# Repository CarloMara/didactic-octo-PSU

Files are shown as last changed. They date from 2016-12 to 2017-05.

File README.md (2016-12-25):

# **Didactic PSU**

**An efficient finals project**

So, @nicogela and I decided to build a LAB PSU, but because we're lazy people and we don't like to carry weight we're tring to unite the high efficiency of the switching topologies to the high stability and low noise of the linear ones.

Up until now we've designed the linear stage, and we added to it some DACs in oreder to controll it with a uC. The next stage in the design process will be the testing of the linear + the dacs. If everithing works we will go ahead adding to the desing the switching stage.

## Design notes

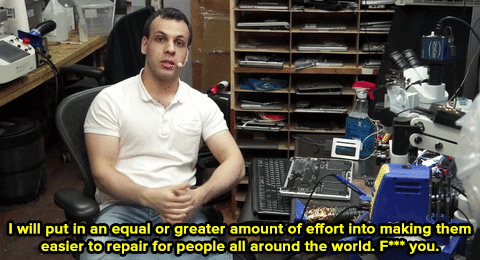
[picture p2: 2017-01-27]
datasheet-docs/low_voltage_switching/fuck_you.gif

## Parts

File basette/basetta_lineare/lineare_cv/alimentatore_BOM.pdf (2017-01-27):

alimentatore

Refs | Value
C14;C12;C13 | .33u
C2 | 0
C3 | 180p
C18 | 18p
C4 | 2200p
C5 | 6.8u
C1 | 1000u
C6 | 470u
C8;C7 | NP
C11;C10;C16;C17;C9;C15470u
D1;D3;D2;D6;D8;D4;D5 | 1N4148
D7 | D_Small
U3 | LM393
U1;U2;U4 | LM741
P8;P9 | CONN_01X01
J10 | TP1
J11 | TP2
J12 | TP3
J2 | TP5
J1 | TP6
J3 | TP7
P5 | CONN_01X02
P4;P7 | CONN_01X03
P3 | CONN_01X04
RV1;RV2 | 10K
RV3 | 50K
U7 | LM7805CT
U8 | LM7812CT
U9 | LM7912CT
R29;R28 | 1K
R2;R7;R21 | 0
R19 | 0,1
R17 | 1
R26 | 100K
R20;R22 | 10K
R9;R13;R23 | 1K
R4 | 1K2
R6 | 1M5
R8;R10 | 2,5K
R12 | 21,5
R2 | 2K
R16 | 390
R24 | 4,64K
R3 | 50
R18 | 500K
R11 | 50K
R5 | 5K
R15 | 6,81K
R27 | 900K
R25 | NP
R14 | R
L1 | 0

Q1 | Q_NMOS_GDS
Q2 | Q_PNP_EBC
P1 | LOAD_POWER_01X02
P2 | CONN_01X03
P6 | LOGIC_POWER_01X03

Footprint | QTY | MFR | MPN | SPR | SPN
Capacitors_ThroughHole:C_Disc_D3_P2.5 | 3
Capacitors_ThroughHole:C_Disc_D3_P2.5 | 1
Capacitors_ThroughHole:C_Disc_D3_P2.5 | 1
Capacitors_ThroughHole:C_Disc_D3_P2.5 | 1
Capacitors_ThroughHole:C_Disc_D3_P2.5 | 1
Capacitors_ThroughHole:C_Disc_D3_P2.5 | 1
Capacitors_ThroughHole:C_Radial_D14_L31.5_P5 | 1
Capacitors_ThroughHole:C_Radial_D14_L31.5_P5 | 1
Capacitors_ThroughHole:C_Radial_D7.5_L11.2_P2.5 | 2
Capacitors_ThroughHole:C_Radial_D8_L21_P3.8 | 6
Diodes_ThroughHole:Diode_DO-41_SOD81_Vertical_AnodeUp | 7
Diodes_ThroughHole:Diode_DO-41_SOD81_Vertical_AnodeUp | 1
Housings_DIP:DIP-8_W7.62mm_LongPads | 1
Housings_DIP:DIP-8_W7.62mm_LongPads | 3
Pin_Headers:Pin_Header_Straight_1x01 | 2
Pin_Headers:Pin_Header_Straight_1x01 | 1
Pin_Headers:Pin_Header_Straight_1x01 | 1
Pin_Headers:Pin_Header_Straight_1x01 | 1
Pin_Headers:Pin_Header_Straight_1x01 | 1
Pin_Headers:Pin_Header_Straight_1x01 | 1
Pin_Headers:Pin_Header_Straight_1x01 | 1
Pin_Headers:Pin_Header_Straight_1x02 | 1
Pin_Headers:Pin_Header_Straight_1x03 | 2
Pin_Headers:Pin_Header_Straight_1x04 | 1
Potentiometers:Potentiometer_Trimmer-Piher-PT15-h5_vertical | 2
Potentiometers:Potentiometer_Trimmer-Piher-PT15-h5_vertical | 1
Power_Integrations:TO-220 | 1
Power_Integrations:TO-220 | 1
Power_Integrations:TO-220 | 1
Resistors_SMD:R_1210_HandSoldering | 2
Resistors_ThroughHole:Resistor_Horizontal_RM10mm | 3
Resistors_ThroughHole:Resistor_Horizontal_RM10mm | 1
Resistors_ThroughHole:Resistor_Horizontal_RM10mm | 1
Resistors_ThroughHole:Resistor_Horizontal_RM10mm | 1
Resistors_ThroughHole:Resistor_Horizontal_RM10mm | 2
Resistors_ThroughHole:Resistor_Horizontal_RM10mm | 3
Resistors_ThroughHole:Resistor_Horizontal_RM10mm | 1
Resistors_ThroughHole:Resistor_Horizontal_RM10mm | 1
Resistors_ThroughHole:Resistor_Horizontal_RM10mm | 2
Resistors_ThroughHole:Resistor_Horizontal_RM10mm | 1
Resistors_ThroughHole:Resistor_Horizontal_RM10mm | 1
Resistors_ThroughHole:Resistor_Horizontal_RM10mm | 1
Resistors_ThroughHole:Resistor_Horizontal_RM10mm | 1
Resistors_ThroughHole:Resistor_Horizontal_RM10mm | 1
Resistors_ThroughHole:Resistor_Horizontal_RM10mm | 1
Resistors_ThroughHole:Resistor_Horizontal_RM10mm | 1
Resistors_ThroughHole:Resistor_Horizontal_RM10mm | 1
Resistors_ThroughHole:Resistor_Horizontal_RM10mm | 1
Resistors_ThroughHole:Resistor_Horizontal_RM10mm | 1
Resistors_ThroughHole:Resistor_Horizontal_RM10mm | 1
Resistors_ThroughHole:Resistor_Horizontal_RM10mm | 1
Resistors_ThroughHole:Resistor_Horizontal_RM7mm | 1

TO_SOT_Packages_THT:TO-220_Neutral123_Vertical_LargePad | 1
TO_SOT_Packages_THT:TO-92_Rugged | 1
w_conn_screw:mors_2p | 1
w_conn_screw:mors_3p | 1
w_conn_screw:mors_3p | 1

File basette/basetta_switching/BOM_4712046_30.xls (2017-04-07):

Part | Manufacturer | Part Number | Quantity | Price | Attribute 1 Name | Attribute 1 Value | Attribute 2 Name | Attribute 2 Value | Attribute 3 Name | Attribute 3 Value | Footprint
Cbias | TDK | C3216X7R2A105M160AA | 1 | 0.11 |  | CAP CER 1UF 100V X7R 1206 |  |  |  |  | 1206
Cboot1 | Kemet | C0603C104K3RACTU | 1 | 0.01 |  | CAP CER 0.1UF 25V X7R 0603 |  |  |  |  | 603
Cboot2 | Kemet | C0603C104K3RACTU | 1 | 0.01 |  |  |  |  |  |  | 603
Cbulk | Nichicon | UUD1C680MCL1GS | 1 | 0.11 |  | CAP ALUM 68UF 20% 16V SMD |  |  |  |  | SM_RADIAL_6.3AMM
Ccomp | MuRata | GRM033R61A822KA01D | 1 | 0.01 |  | CAP CER 8200PF 10V X5R 0201 |  |  |  |  | 201
Ccomp2 | Kemet | C0805C270K5GACTU | 1 | 0.01 |  | CAP CER 27PF 50V NP0 0805 |  |  |  |  | 805
Ccs | AVX | 06035A470JAT2A | 1 | 0.01 |  | CAP CER 47PF 50V NP0 0603 |  |  |  |  | 603
Cf | TDK | C1608X5R1H224K080AB | 1 | 0.03 |  | CAP CER 0.22UF 50V X5R 0603 |  |  |  |  | 603
Cin | MuRata | GRM31CR71E106KA12L | 1 | 0.05 |  | CAP CER 10UF 25V X7R 1206 |  |  |  |  | 1206_190
Cout | TDK | CGA9P3X7S2A156M250KB | 2 | 1.24 |  | CAP CER 15UF 100V X7S 2220 |  |  |  |  | 2220_280
Coutx | TDK | C5750X7R2A475M | 5 | 0.67 |  | CAP CER 4.7UF 100V X7R 2220 |  |  |  |  | 2220
Coutx2 | TDK | C5750X7R2A475M | 5 | 0.67 |  |  |  |  |  |  | 2220
Coutx3 | TDK | C5750X7R2A475M | 5 | 0.67 |  |  |  |  |  |  | 2220
Cslope | Yageo America | CC0603JRNPO9BN271 | 1 | 0.01 |  | CAP CER 270PF 50V NPO 0603 |  |  |  |  | 603
Css | Kemet | C0603C223K3RACTU | 1 | 0.01 |  | CAP CER 0.022UF 25V X7R 0603 |  |  |  |  | 603
Cvcc | MuRata | GRM188R61C105KA93D | 1 | 0.01 |  | CAP CER 1UF 16V X5R 0603 |  |  |  |  | 603
D2 | Fairchild Semiconductor | SS24FL | 1 | 0.07 | VFatIo | 0.55V | Io | 2A | VRRM | 40V | SOD-123F
D3 | Diodes Inc. | B260-13-F | 1 | 0.09 | VFatIo | 0.7V | Io | 2A | VRRM | 60V | SMB
Dboot1 | Fairchild Semiconductor | SS24FL | 1 | 0.07 | VFatIo | 0.55V | Io | 2A | VRRM | 40V | SOD-123F
Dboot2 | Fairchild Semiconductor | SS24FL | 1 | 0.07 | VFatIo | 0.55V | Io | 2A | VRRM | 40V | SOD-123F
Df | Fairchild Semiconductor | SS24FL | 1 | 0.07 | VFatIo | 0.55V | Io | 2A | VRRM | 40V | SOD-123F
L1 | Coilcraft | XAL1010-822MEB | 1 | 1.71 | L | 8.2uH | DCR | 0.012Ohm | IDC | 17.1A | XAL1010
M1 | Texas Instruments | CSD16323Q3 | 1 | 0.36 | VdsMax | 25V | IdsMax | 60A | Rdson | 4.4mOhm | DQG0008A
M2 | Texas Instruments | CSD16323Q3 | 1 | 0.36 | VdsMax | 25V | IdsMax | 60A | Rdson | 4.4mOhm | DQG0008A
M3 | Texas Instruments | CSD19534Q5A | 1 | 0.34 | VdsMax | 100V | IdsMax | 50A | Rdson | 0.014Ohm | TRANS_NexFET_Q5A
M4 | Texas Instruments | CSD18531Q5A | 1 | 0.58 | VdsMax | 60V | IdsMax | 100A | Rdson | 5.8mOhm | TRANS_NexFET_Q5A
Rcomp | Vishay-Dale | CRCW040241K2FKED | 1 | 0.01 | Resistance | 41.2kOhm | Tolerance | 1% | Power | 0.063W | 402
Rcsg | Vishay-Dale | CRCW0603100RFKEA | 1 | 0.01 | Resistance | 100Ohm | Tolerance | 1% | Power | 0.1W | 603
Rcsp | Vishay-Dale | CRCW0603100RFKEA | 1 | 0.01 | Resistance | 100Ohm | Tolerance | 1% | Power | 0.1W | 603
Rf | Vishay-Dale | CRCW060310R0FKEA | 1 | 0.01 | Resistance | 10Ohm | Tolerance | 1% | Power | 0.1W | 603
Rfbb | Vishay-Dale | CRCW060320K0FKEA | 1 | 0.01 | Resistance | 20kOhm | Tolerance | 1% | Power | 0.1W | 603
Rfbt | Vishay-Dale | CRCW06031M18FKEA | 1 | 0.01 | Resistance | 1.18MOhm | Tolerance | 1% | Power | 0.1W | 603
Rpg | Vishay-Dale | CRCW060320K0FKEA | 1 | 0.01 | Resistance | 20kOhm | Tolerance | 1% | Power | 0.1W | 603
Rsense | Vishay-Dale | WSR39L000FEA | 1 | 0.64 | Resistance | 9mOhm | Tolerance | 1% | Power | 3W | 4527
Rt | Vishay-Dale | CRCW040290K9FKED | 1 | 0.01 | Resistance | 90.9kOhm | Tolerance | 1% | Power | 0.063W | 402
Ruvb | Vishay-Dale | CRCW040232K4FKED | 1 | 0.01 | Resistance | 32.4kOhm | Tolerance | 1% | Power | 0.063W | 402
Ruvt | Vishay-Dale | CRCW0402249KFKED | 1 | 0.01 | Resistance | 249kOhm | Tolerance | 1% | Power | 0.063W | 402
U1 | Texas Instruments | LM5175PWPR | 1 | 3.1 |  |  |  |  |  |  | PWP0028F_N
Rmode | Vishay-Dale | CRCW060393K1FKEA | 1 | 0.01 | Resistance | 93.1kOhm | Tolerance | 1% | Power | 0.1W | 603

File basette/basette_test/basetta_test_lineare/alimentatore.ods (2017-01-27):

Refs | Value | Footprint | QTY | MFR | MPN | SPR | SPN
C14;C12;C13 | .33u | Capacitors_ThroughHole:C_Disc_D3_P2.5 | 3
C2 | 0 | Capacitors_ThroughHole:C_Disc_D3_P2.5 | 1
C3 | 180p | Capacitors_ThroughHole:C_Disc_D3_P2.5 | 1
C18 | 18p | Capacitors_ThroughHole:C_Disc_D3_P2.5 | 1
C4 | 2200p | Capacitors_ThroughHole:C_Disc_D3_P2.5 | 1
C5 | 6.8u | Capacitors_ThroughHole:C_Disc_D3_P2.5 | 1
C1 | 1000u | Capacitors_ThroughHole:C_Radial_D14_L31.5_P5 | 1
C6 | 470u | Capacitors_ThroughHole:C_Radial_D14_L31.5_P5 | 1
C8;C7 | NP | Capacitors_ThroughHole:C_Radial_D7.5_L11.2_P2.5 | 2
C11;C10;C16;C17;C9;C15 | 470u | Capacitors_ThroughHole:C_Radial_D8_L21_P3.8 | 6
D1;D3;D2;D6;D8;D4;D5 | 1N4148 | Diodes_ThroughHole:Diode_DO-41_SOD81_Vertical_AnodeUp | 7
D7 | D_Small | Diodes_ThroughHole:Diode_DO-41_SOD81_Vertical_AnodeUp | 1
U3 | LM393 | Housings_DIP:DIP-8_W7.62mm_LongPads | 1
U1;U2;U4 | LM741 | Housings_DIP:DIP-8_W7.62mm_LongPads | 3
P8;P9 | CONN_01X01 | Pin_Headers:Pin_Header_Straight_1x01 | 2
J10 | TP1 | Pin_Headers:Pin_Header_Straight_1x01 | 1
J11 | TP2 | Pin_Headers:Pin_Header_Straight_1x01 | 1
J12 | TP3 | Pin_Headers:Pin_Header_Straight_1x01 | 1
J2 | TP5 | Pin_Headers:Pin_Header_Straight_1x01 | 1
J1 | TP6 | Pin_Headers:Pin_Header_Straight_1x01 | 1
J3 | TP7 | Pin_Headers:Pin_Header_Straight_1x01 | 1
P5 | CONN_01X02 | Pin_Headers:Pin_Header_Straight_1x02 | 1
P4;P7 | CONN_01X03 | Pin_Headers:Pin_Header_Straight_1x03 | 2
P3 | CONN_01X04 | Pin_Headers:Pin_Header_Straight_1x04 | 1
RV1;RV2 | 10K | Potentiometers:Potentiometer_Trimmer-Piher-PT15-h5_vertical | 2
RV3 | 50K | Potentiometers:Potentiometer_Trimmer-Piher-PT15-h5_vertical | 1
U7 | LM7805CT | Power_Integrations:TO-220 | 1
U8 | LM7812CT | Power_Integrations:TO-220 | 1
U9 | LM7912CT | Power_Integrations:TO-220 | 1
R29;R28 | 1K | Resistors_SMD:R_1210_HandSoldering | 2
R2;R7;R21 | 0 | Resistors_ThroughHole:Resistor_Horizontal_RM10mm | 3
R19 | 0,1 | Resistors_ThroughHole:Resistor_Horizontal_RM10mm | 1
R17 | 1 | Resistors_ThroughHole:Resistor_Horizontal_RM10mm | 1
R26 | 100K | Resistors_ThroughHole:Resistor_Horizontal_RM10mm | 1
R20;R22 | 10K | Resistors_ThroughHole:Resistor_Horizontal_RM10mm | 2
R9;R13;R23 | 1K | Resistors_ThroughHole:Resistor_Horizontal_RM10mm | 3
R4 | 1K2 | Resistors_ThroughHole:Resistor_Horizontal_RM10mm | 1
R6 | 1M5 | Resistors_ThroughHole:Resistor_Horizontal_RM10mm | 1
R8;R10 | 2,5K | Resistors_ThroughHole:Resistor_Horizontal_RM10mm | 2
R12 | 21,5 | Resistors_ThroughHole:Resistor_Horizontal_RM10mm | 1
R2 | 2K | Resistors_ThroughHole:Resistor_Horizontal_RM10mm | 1
R16 | 390 | Resistors_ThroughHole:Resistor_Horizontal_RM10mm | 1
R24 | 4,64K | Resistors_ThroughHole:Resistor_Horizontal_RM10mm | 1
R3 | 50 | Resistors_ThroughHole:Resistor_Horizontal_RM10mm | 1
R18 | 500K | Resistors_ThroughHole:Resistor_Horizontal_RM10mm | 1
R11 | 50K | Resistors_ThroughHole:Resistor_Horizontal_RM10mm | 1
R5 | 5K | Resistors_ThroughHole:Resistor_Horizontal_RM10mm | 1
R15 | 6,81K | Resistors_ThroughHole:Resistor_Horizontal_RM10mm | 1
R27 | 900K | Resistors_ThroughHole:Resistor_Horizontal_RM10mm | 1
R25 | NP | Resistors_ThroughHole:Resistor_Horizontal_RM10mm | 1
R14 | R | Resistors_ThroughHole:Resistor_Horizontal_RM10mm | 1
L1 | 0 | Resistors_ThroughHole:Resistor_Horizontal_RM7mm | 1
Q1 | Q_NMOS_GDS | TO_SOT_Packages_THT:TO-220_Neutral123_Vertical_LargePads | 1
Q2 | Q_PNP_EBC | TO_SOT_Packages_THT:TO-92_Rugged | 1
P1 | LOAD_POWER_01X02 | w_conn_screw:mors_2p | 1
P2 | CONN_01X03 | w_conn_screw:mors_3p | 1
P6 | LOGIC_POWER_01X03 | w_conn_screw:mors_3p | 1

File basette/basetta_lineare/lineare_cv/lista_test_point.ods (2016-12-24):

TEST POINT | FUNZIONE
#
TP1 | Linea alimentazione +5V. Da questo dipendono tutti gli integrati attaccati alla linea +5V
TP2 | Linea alimentazione +12V. Da questo dipendono tutti gli integrati attaccati alla linea +12VA
TP3 | Linea alimentazione -12V. Da questo dipendono tutti gli integrati attaccati alla linea -12VA
TP4 | Riferimento DAC
TP5 | Tensione di polarizzazione pnp driver
TP6 | Tensione gate mosfet
TP7 | Tensione resistenza di shunt
TP8 | Ingresso ADC per lettura correte
TP9 | Ingresso ADC per lettura tensione
TP10 | I2C bus linea SCL
TP11 | I2C bus linea SDA

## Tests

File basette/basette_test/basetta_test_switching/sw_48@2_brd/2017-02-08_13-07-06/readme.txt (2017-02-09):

 

**********************************************************
*************  Important Instructions Follow  ************
**********************************************************
 
All files exported to: Z:\\47\\12\\4712046\\29\Eagle\2017-02-08_13-07-06\2017-02-08_13-07-06.xml

**********************************************************
*****************Schematic Instructions  *******************
**********************************************************

To import your new Schematic file into Eagle:

1. Unzip the downloaded folder files to local directory and Start Eagle.
2. Select "File"->"Open"->"Schematic..." from the menu at the top of
the screen.
3. Browse to your newly exported file and select the ".sch" file extension.
4. You should now see your schamtic available in Eagle.

**********************************************************
*******************  PCB Instructions  *******************
**********************************************************

To import your new BOARD file into Eagle:

1. Unzip the downloaded folder files to local directory and Start Eagle.
2. Select "File"->"Open"->"Board..." from the menu at the top of
the screen.
3. Browse to your newly exported file and select the ".brd" file extension.
4. Planes will need to be repoured to update the polygon fills
	1. Once your board is loaded, type "ratsnest" into the command
	   line and press the Enter key.
	2. The polygons should all be filled now.
5. You should now have an image of your board available in Eagle.

**********************************************************
*******************  LIB Instructions  *******************
**********************************************************

To import your new library into Eagle:

1. Start Eagle.
2. Select "File"->"New"->"Library" from the menu.
3. In the blank library window, select "File" -> "Execute Script"
from the menu.
5. Browse to your newly exported Eagle Script file (".scr" file extension)
6. After opening the file, the script will populate the new library.
Layer 93 should NOT exist.
7. Use "File"->Save As: "AcceleratedDesigns_Lib.lbr" and to the desired
location in Eagle native format.
8. Update schematic with the imported library, Select Library and click on Update; open the library file
	and sync. each part.

For additional information, please visit this site:
http://www.accelerated-designs.com/help/Eagle_import.html

You may also find this video helpful:
http://youtu.be/5jGuWY-Yy3Q

**********************************************************
**********************************************************
**********************************************************

Component "C3216X7R2A105M160AA" renamed to "C3216X7R2A105M160AA"
Component "C0603C104K3RACTU" renamed to "C0603C104K3RACTU"
Component "UUD1C680MCL1GS" renamed to "UUD1C680MCL1GS"
Component "GRM033R61A822KA01D" renamed to "GRM033R61A822KA01D"
Component "C0805C270K5GACTU" renamed to "C0805C270K5GACTU"
Component "06035A470JAT2A" renamed to "06035A470JAT2A"
Component "GRM31CR71E106KA12L" renamed to "GRM31CR71E106KA12L"
Component "C1608X5R1H224K080AB" renamed to "C1608X5R1H224K080AB"
Component "C0603C223K3RACTU" renamed to "C0603C223K3RACTU"
Component "CGA9P3X7S2A156M250KB" renamed to "CGA9P3X7S2A156M250KB"
Component "C5750X7R2A475M" renamed to "C5750X7R2A475M"
Component "CC0603JRNPO9BN271" renamed to "CC0603JRNPO9BN271"
Component "C0805C224K5RACTU" renamed to "C0805C224K5RACTU"
Component "GRM188R61C105KA93D" renamed to "GRM188R61C105KA93D"
Component "B260-13-F" renamed to "B260-13-F"
Component "SS24FL" renamed to "SS24FL"
Component "LM5175PWPR" renamed to "LM5175PWPR"
Component "XAL1010-822MEB" renamed to "XAL1010-822MEB"
Component "CSD16323Q3" renamed to "CSD16323Q3"
Component "CSD19534Q5A" renamed to "CSD19534Q5A"
Component "CSD18531Q5A" renamed to "CSD18531Q5A"
Component "CRCW040241K2FKED" renamed to "CRCW040241K2FKED"
Component "CRCW0603100RFKEA" renamed to "CRCW0603100RFKEA"
Component "CRCW060310R0FKEA" renamed to "CRCW060310R0FKEA"
Component "CRCW060393K1FKEA" renamed to "CRCW060393K1FKEA"
Component "CRCW06031M18FKEA" renamed to "CRCW06031M18FKEA"
Component "CRA2512-FZ-R050ELF" renamed to "CRA2512-FZ-R050ELF"
Component "ERJ-6ENF1583V" renamed to "ERJ-6ENF1583V"
Component "CRCW060320K0FKEA" renamed to "CRCW060320K0FKEA"
Component "WSR39L000FEA" renamed to "WSR39L000FEA"
Component "CRCW040290K9FKED" renamed to "CRCW040290K9FKED"
Component "CRCW040232K4FKED" renamed to "CRCW040232K4FKED"
Component "CRCW0402249KFKED" renamed to "CRCW0402249KFKED"
Component "TP-1502" renamed to "TP-1502"

Ultra Librarian Gold 8.1.204 Process Report

Message - Padstack "R10630430000200A" Shape(4) is a CIRCLE with no diameter.
Message - Padstack "RX26Y38D0T" Shape(4) is a CIRCLE with no diameter.
Message - Padstack "RX128Y31D0T" Shape(4) is a CIRCLE with no diameter.
Message - Padstack "RX14Y13D0T" Shape(4) is a CIRCLE with no diameter.
Message - Padstack "RX44Y57D0T" Shape(4) is a CIRCLE with no diameter.
Message - Padstack "RX44Y71D0T" Shape(4) is a CIRCLE with no diameter.
Message - Padstack "RX45Y213D0T" Shape(4) is a CIRCLE with no diameter.
Message - Padstack "R10470470000202A" Shape(4) is a CIRCLE with no diameter.
Message - Padstack "RX71Y81D0T" Shape(4) is a CIRCLE with no diameter.
Message - Padstack "RX94Y445D0T" Shape(4) is a CIRCLE with no diameter.
Message - Padstack "R10200250000209A" Shape(4) is a CIRCLE with no diameter.
Message - Padstack "RX31p5Y27p56D0T" Shape(4) is a CIRCLE with no diameter.
Message - Padstack "RX4p3Y4p56D0T" Shape(4) is a CIRCLE with no diameter.
Message - Padstack "RX22Y24D0T" Shape(4) is a CIRCLE with no diameter.
Message - Padstack "RX56Y107D0T" Shape(4) is a CIRCLE with no diameter.
Message - Padstack "RX124Y220D0T" Shape(4) is a CIRCLE with no diameter.
Message - Padstack "O1014067000P0204" Shape(4) is a CIRCLE with no diameter.
Message - Padstack "R1122204000P0204" Shape(4) is a CIRCLE with no diameter.
Message - Component "C3216X7R2A105M160AA" attribute "Datasheet URL" references text style "" that is not in the database.
The default pattern text style "H50s3" was substituted.
Message - Component "C3216X7R2A105M160AA" attribute "Cap" references text style "" that is not in the database.
The default pattern text style "H50s3" was substituted.
Message - Component "C3216X7R2A105M160AA" attribute "ESR" references text style "" that is not in the database.
The default pattern text style "H50s3" was substituted.
Message - Component "C3216X7R2A105M160AA" attribute "IRMS" references text style "" that is not in the database.
The default pattern text style "H50s3" was substituted.
Message - Component "C3216X7R2A105M160AA" attribute "VDC" references text style "" that is not in the database.
The default pattern text style "H50s3" was substituted.
Message - Component "C0603C104K3RACTU" attribute "Cap" references text style "" that is not in the database.
The default pattern text style "H50s3" was substituted.
Message - Component "C0603C104K3RACTU" attribute "ESR" references text style "" that is not in the database.
The default pattern text style "H50s3" was substituted.
Message - Component "C0603C104K3RACTU" attribute "IRMS" references text style "" that is not in the database.
The default pattern text style "H50s3" was substituted.
Message - Component "C0603C104K3RACTU" attribute "VDC" references text style "" that is not in the database.
The default pattern text style "H50s3" was substituted.
Message - Component "UUD1C680MCL1GS" attribute "Cap" references text style "" that is not in the database.
The default pattern text style "H50s3" was substituted.
Message - Component "UUD1C680MCL1GS" attribute "ESR" references text style "" that is not in the database.
The default pattern text style "H50s3" was substituted.
Message - Component "UUD1C680MCL1GS" attribute "IRMS" references text style "" that is not in the database.
The default pattern text style "H50s3" was substituted.
Message - Component "UUD1C680MCL1GS" attribute "VDC" references text style "" that is not in the database.
The default pattern text style "H50s3" was substituted.
Message - Component "GRM033R61A822KA01D" attribute "Cap" references text style "" that is not in the database.
The default pattern text style "H50s3" was substituted.
Message - Component "GRM033R61A822KA01D" attribute "ESR" references text style "" that is not in the database.
The default pattern text style "H50s3" was substituted.
Message - Component "GRM033R61A822KA01D" attribute "IRMS" references text style "" that is not in the database.
The default pattern text style "H50s3" was substituted.
Message - Component "GRM033R61A822KA01D" attribute "VDC" references text style "" that is not in the database.
The default pattern text style "H50s3" was substituted.
Message - Component "C0805C270K5GACTU" attribute "Datasheet URL" references text style "" that is not in the database.
The default pattern text style "H50s3" was substituted.
Message - Component "C0805C270K5GACTU" attribute "Cap" references text style "" that is not in the database.
The default pattern text style "H50s3" was substituted.
Message - Component "C0805C270K5GACTU" attribute "ESR" references text style "" that is not in the database.
The default pattern text style "H50s3" was substituted.
Message - Component "C0805C270K5GACTU" attribute "IRMS" references text style "" that is not in the database.
The default pattern text style "H50s3" was substituted.
Message - Component "C0805C270K5GACTU" attribute "VDC" references text style "" that is not in the database.
The default pattern text style "H50s3" was substituted.
Message - Component "06035A470JAT2A" attribute "Cap" references text style "" that is not in the database.
The default pattern text style "H50s3" was substituted.
Message - Component "06035A470JAT2A" attribute "ESR" references text style "" that is not in the database.
The default pattern text style "H50s3" was substituted.
Message - Component "06035A470JAT2A" attribute "IRMS" references text style "" that is not in the database.
The default pattern text style "H50s3" was substituted.
Message - Component "06035A470JAT2A" attribute "VDC" references text style "" that is not in the database.
The default pattern text style "H50s3" was substituted.
Message - Component "GRM31CR71E106KA12L" attribute "Cap" references text style "" that is not in the database.
The default pattern text style "H50s3" was substituted.
Message - Component "GRM31CR71E106KA12L" attribute "ESR" references text style "" that is not in the database.
The default pattern text style "H50s3" was substituted.
Message - Component "GRM31CR71E106KA12L" attribute "IRMS" references text style "" that is not in the database.
The default pattern text style "H50s3" was substituted.
Message - Component "GRM31CR71E106KA12L" attribute "VDC" references text style "" that is not in the database.
The default pattern text style "H50s3" was substituted.
Message - Component "C1608X5R1H224K080AB" attribute "Datasheet URL" references text style "" that is not in the database.
The default pattern text style "H50s3" was substituted.
Message - Component "C1608X5R1H224K080AB" attribute "Cap" references text style "" that is not in the database.
The default pattern text style "H50s3" was substituted.
Message - Component "C1608X5R1H224K080AB" attribute "ESR" references text style "" that is not in the database.
The default pattern text style "H50s3" was substituted.
Message - Component "C1608X5R1H224K080AB" attribute "IRMS" references text style "" that is not in the database.
The default pattern text style "H50s3" was substituted.
Message - Component "C1608X5R1H224K080AB" attribute "VDC" references text style "" that is not in the database.
The default pattern text style "H50s3" was substituted.
Message - Component "C0603C223K3RACTU" attribute "Cap" references text style "" that is not in the database.
The default pattern text style "H50s3" was substituted.
Message - Component "C0603C223K3RACTU" attribute "ESR" references text style "" that is not in the database.
The default pattern text style "H50s3" was substituted.
Message - Component "C0603C223K3RACTU" attribute "IRMS" references text style "" that is not in the database.
The default pattern text style "H50s3" was substituted.
Message - Component "C0603C223K3RACTU" attribute "VDC" references text style "" that is not in the database.
The default pattern text style "H50s3" was substituted.
Message - Component "CGA9P3X7S2A156M250KB" attribute "Datasheet URL" references text style "" that is not in the database.
The default pattern text style "H50s3" was substituted.
Message - Component "CGA9P3X7S2A156M250KB" attribute "Cap" references text style "" that is not in the database.
The default pattern text style "H50s3" was substituted.
Message - Component "CGA9P3X7S2A156M250KB" attribute "ESR" references text style "" that is not in the database.
The default pattern text style "H50s3" was substituted.
Message - Component "CGA9P3X7S2A156M250KB" attribute "IRMS" references text style "" that is not in the database.
The default pattern text style "H50s3" was substituted.
Message - Component "CGA9P3X7S2A156M250KB" attribute "VDC" references text style "" that is not in the database.
The default pattern text style "H50s3" was substituted.
Message - Component "C5750X7R2A475M" attribute "Datasheet URL" references text style "" that is not in the database.
The default pattern text style "H50s3" was substituted.
Message - Component "C5750X7R2A475M" attribute "Cap" references text style "" that is not in the database.
The default pattern text style "H50s3" was substituted.
Message - Component "C5750X7R2A475M" attribute "ESR" references text style "" that is not in the database.
The default pattern text style "H50s3" was substituted.
Message - Component "C5750X7R2A475M" attribute "IRMS" references text style "" that is not in the database.
The default pattern text style "H50s3" was substituted.
Message - Component "C5750X7R2A475M" attribute "VDC" references text style "" that is not in the database.
The default pattern text style "H50s3" was substituted.
Message - Component "CC0603JRNPO9BN271" attribute "Datasheet URL" references text style "" that is not in the database.
The default pattern text style "H50s3" was substituted.
Message - Component "CC0603JRNPO9BN271" attribute "Cap" references text style "" that is not in the database.
The default pattern text style "H50s3" was substituted.
Message - Component "CC0603JRNPO9BN271" attribute "ESR" references text style "" that is not in the database.
The default pattern text style "H50s3" was substituted.
Message - Component "CC0603JRNPO9BN271" attribute "IRMS" references text style "" that is not in the database.
The default pattern text style "H50s3" was substituted.
Message - Component "CC0603JRNPO9BN271" attribute "VDC" references text style "" that is not in the database.
The default pattern text style "H50s3" was substituted.
Message - Component "C0805C224K5RACTU" attribute "Cap" references text style "" that is not in the database.
The default pattern text style "H50s3" was substituted.
Message - Component "C0805C224K5RACTU" attribute "ESR" references text style "" that is not in the database.
The default pattern text style "H50s3" was substituted.
Message - Component "C0805C224K5RACTU" attribute "IRMS" references text style "" that is not in the database.
The default pattern text style "H50s3" was substituted.
Message - Component "C0805C224K5RACTU" attribute "VDC" references text style "" that is not in the database.
The default pattern text style "H50s3" was substituted.
Message - Component "GRM188R61C105KA93D" attribute "Cap" references text style "" that is not in the database.
The default pattern text style "H50s3" was substituted.
Message - Component "GRM188R61C105KA93D" attribute "ESR" references text style "" that is not in the database.
The default pattern text style "H50s3" was substituted.
Message - Component "GRM188R61C105KA93D" attribute "IRMS" references text style "" that is not in the database.
The default pattern text style "H50s3" was substituted.
Message - Component "GRM188R61C105KA93D" attribute "VDC" references text style "" that is not in the database.
The default pattern text style "H50s3" was substituted.
Message - Component "B260-13-F" attribute "Datasheet URL" references text style "" that is not in the database.
The default pattern text style "H50s3" was substituted.
Message - Component "B260-13-F" attribute "Io" references text style "" that is not in the database.
The default pattern text style "H50s3" was substituted.
Message - Component "B260-13-F" attribute "VRRM" references text style "" that is not in the database.
The default pattern text style "H50s3" was substituted.
Message - Component "B260-13-F" attribute "VFatIo" references text style "" that is not in the database.
The default pattern text style "H50s3" was substituted.
Message - Component "SS24FL" attribute "Datasheet URL" references text style "" that is not in the database.
The default pattern text style "H50s3" was substituted.
Message - Component "SS24FL" attribute "Io" references text style "" that is not in the database.
The default pattern text style "H50s3" was substituted.
Message - Component "SS24FL" attribute "VRRM" references text style "" that is not in the database.
The default pattern text style "H50s3" was substituted.
Message - Component "SS24FL" attribute "VFatIo" references text style "" that is not in the database.
The default pattern text style "H50s3" was substituted.
Message - Component "XAL1010-822MEB" attribute "L" references text style "" that is not in the database.
The default pattern text style "H50s3" was substituted.
Message - Component "XAL1010-822MEB" attribute "DCR" references text style "" that is not in the database.
The default pattern text style "H50s3" was substituted.
Message - Component "XAL1010-822MEB" attribute "IDC" references text style "" that is not in the database.
The default pattern text style "H50s3" was substituted.
Message - Component "CSD16323Q3" attribute "Datasheet URL" references text style "" that is not in the database.
The default pattern text style "H50s3" was substituted.
Message - Component "CSD16323Q3" attribute "VdsMax" references text style "" that is not in the database.
The default pattern text style "H50s3" was substituted.
Message - Component "CSD16323Q3" attribute "IdsMax" references text style "" that is not in the database.
The default pattern text style "H50s3" was substituted.
Message - Component "CSD16323Q3" attribute "Rdson45" references text style "" that is not in the database.
The default pattern text style "H50s3" was substituted.
Message - Component "CSD16323Q3" attribute "QgTyp" references text style "" that is not in the database.
The default pattern text style "H50s3" was substituted.
Message - Component "CSD16323Q3" attribute "Quantity" references text style "" that is not in the database.
The default pattern text style "H50s3" was substituted.
Message - Component "CSD18531Q5A" attribute "Datasheet URL" references text style "" that is not in the database.
The default pattern text style "H50s3" was substituted.
Message - Component "CSD18531Q5A" attribute "VdsMax" references text style "" that is not in the database.
The default pattern text style "H50s3" was substituted.
Message - Component "CSD18531Q5A" attribute "IdsMax" references text style "" that is not in the database.
The default pattern text style "H50s3" was substituted.
Message - Component "CSD18531Q5A" attribute "Rdson45" references text style "" that is not in the database.
The default pattern text style "H50s3" was substituted.
Message - Component "CSD18531Q5A" attribute "QgTyp" references text style "" that is not in the database.
The default pattern text style "H50s3" was substituted.
Message - Component "CSD18531Q5A" attribute "Quantity" references text style "" that is not in the database.
The default pattern text style "H50s3" was substituted.
Message - Component "CRCW040241K2FKED" attribute "Resistance" references text style "" that is not in the database.
The default pattern text style "H50s3" was substituted.
Message - Component "CRCW040241K2FKED" attribute "Power" references text style "" that is not in the database.
The default pattern text style "H50s3" was substituted.
Message - Component "CRCW040241K2FKED" attribute "Tolerance" references text style "" that is not in the database.
The default pattern text style "H50s3" was substituted.
Message - Component "CRCW0603100RFKEA" attribute "Resistance" references text style "" that is not in the database.
The default pattern text style "H50s3" was substituted.
Message - Component "CRCW0603100RFKEA" attribute "Power" references text style "" that is not in the database.
The default pattern text style "H50s3" was substituted.
Message - Component "CRCW0603100RFKEA" attribute "Tolerance" references text style "" that is not in the database.
The default pattern text style "H50s3" was substituted.
Message - Component "CRCW060310R0FKEA" attribute "Resistance" references text style "" that is not in the database.
The default pattern text style "H50s3" was substituted.
Message - Component "CRCW060310R0FKEA" attribute "Power" references text style "" that is not in the database.
The default pattern text style "H50s3" was substituted.
Message - Component "CRCW060310R0FKEA" attribute "Tolerance" references text style "" that is not in the database.
The default pattern text style "H50s3" was substituted.
Message - Component "CRCW060393K1FKEA" attribute "Resistance" references text style "" that is not in the database.
The default pattern text style "H50s3" was substituted.
Message - Component "CRCW060393K1FKEA" attribute "Power" references text style "" that is not in the database.
The default pattern text style "H50s3" was substituted.
Message - Component "CRCW060393K1FKEA" attribute "Tolerance" references text style "" that is not in the database.
The default pattern text style "H50s3" was substituted.
Message - Component "CRCW06031M18FKEA" attribute "Resistance" references text style "" that is not in the database.
The default pattern text style "H50s3" was substituted.
Message - Component "CRCW06031M18FKEA" attribute "Power" references text style "" that is not in the database.
The default pattern text style "H50s3" was substituted.
Message - Component "CRCW06031M18FKEA" attribute "Tolerance" references text style "" that is not in the database.
The default pattern text style "H50s3" was substituted.
Message - Component "CRA2512-FZ-R050ELF" attribute "Resistance" references text style "" that is not in the database.
The default pattern text style "H50s3" was substituted.
Message - Component "CRA2512-FZ-R050ELF" attribute "Power" references text style "" that is not in the database.
The default pattern text style "H50s3" was substituted.
Message - Component "CRA2512-FZ-R050ELF" attribute "Tolerance" references text style "" that is not in the database.
The default pattern text style "H50s3" was substituted.
Message - Component "ERJ-6ENF1583V" attribute "Resistance" references text style "" that is not in the database.
The default pattern text style "H50s3" was substituted.
Message - Component "ERJ-6ENF1583V" attribute "Power" references text style "" that is not in the database.
The default pattern text style "H50s3" was substituted.
Message - Component "ERJ-6ENF1583V" attribute "Tolerance" references text style "" that is not in the database.
The default pattern text style "H50s3" was substituted.
Message - Component "CRCW060320K0FKEA" attribute "Resistance" references text style "" that is not in the database.
The default pattern text style "H50s3" was substituted.
Message - Component "CRCW060320K0FKEA" attribute "Power" references text style "" that is not in the database.
The default pattern text style "H50s3" was substituted.
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

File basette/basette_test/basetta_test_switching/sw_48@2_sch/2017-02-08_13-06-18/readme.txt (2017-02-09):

 

**********************************************************
*************  Important Instructions Follow  ************
**********************************************************
 
All files exported to: Z:\\47\\12\\4712046\\29\Eagle\2017-02-08_13-06-18\2017-02-08_13-06-18.xml

**********************************************************
*****************Schematic Instructions  *******************
**********************************************************

To import your new Schematic file into Eagle:

1. Unzip the downloaded folder files to local directory and Start Eagle.
2. Select "File"->"Open"->"Schematic..." from the menu at the top of
the screen.
3. Browse to your newly exported file and select the ".sch" file extension.
4. You should now see your schamtic available in Eagle.

**********************************************************
*******************  PCB Instructions  *******************
**********************************************************

To import your new BOARD file into Eagle:

1. Unzip the downloaded folder files to local directory and Start Eagle.
2. Select "File"->"Open"->"Board..." from the menu at the top of
the screen.
3. Browse to your newly exported file and select the ".brd" file extension.
4. Planes will need to be repoured to update the polygon fills
	1. Once your board is loaded, type "ratsnest" into the command
	   line and press the Enter key.
	2. The polygons should all be filled now.
5. You should now have an image of your board available in Eagle.

**********************************************************
*******************  LIB Instructions  *******************
**********************************************************

To import your new library into Eagle:

1. Start Eagle.
2. Select "File"->"New"->"Library" from the menu.
3. In the blank library window, select "File" -> "Execute Script"
from the menu.
5. Browse to your newly exported Eagle Script file (".scr" file extension)
6. After opening the file, the script will populate the new library.
Layer 93 should NOT exist.
7. Use "File"->Save As: "AcceleratedDesigns_Lib.lbr" and to the desired
location in Eagle native format.
8. Update schematic with the imported library, Select Library and click on Update; open the library file
	and sync. each part.

For additional information, please visit this site:
http://www.accelerated-designs.com/help/Eagle_import.html

You may also find this video helpful:
http://youtu.be/5jGuWY-Yy3Q

**********************************************************
**********************************************************
**********************************************************

Symbol "WB_LM5175_NO_RISNS_COMPONENTS_BLOCK" renamed to "WB_LM5175_NO_RISNS_COMPONENTS_"
Symbol "WB_LM5175_RISNS_COMPONENTS_BLOCK" renamed to "WB_LM5175_RISNS_COMPONENTS_BLO"
Component "C3216X7R2A105M160AA" renamed to "C3216X7R2A105M160AA"
Component "C0603C104K3RACTU" renamed to "C0603C104K3RACTU"
Component "UUD1C680MCL1GS" renamed to "UUD1C680MCL1GS"
Component "GRM033R61A822KA01D" renamed to "GRM033R61A822KA01D"
Component "C0805C270K5GACTU" renamed to "C0805C270K5GACTU"
Component "06035A470JAT2A" renamed to "06035A470JAT2A"
Component "C1608X5R1H224K080AB" renamed to "C1608X5R1H224K080AB"
Component "GRM31CR71E106KA12L" renamed to "GRM31CR71E106KA12L"
Component "WB_CURRENT_LOAD" renamed to "WB_CURRENT_LOAD"
Component "CGA9P3X7S2A156M250KB" renamed to "CGA9P3X7S2A156M250KB"
Component "CC0603JRNPO9BN271" renamed to "CC0603JRNPO9BN271"
Component "C0603C223K3RACTU" renamed to "C0603C223K3RACTU"
Component "GRM188R61C105KA93D" renamed to "GRM188R61C105KA93D"
Component "B260-13-F" renamed to "B260-13-F"
Component "SS24FL" renamed to "SS24FL"
Component "LM5175PWPR" renamed to "LM5175PWPR"
Component "XAL1010-822MEB" renamed to "XAL1010-822MEB"
Component "CSD16323Q3" renamed to "CSD16323Q3"
Component "CSD19534Q5A" renamed to "CSD19534Q5A"
Component "CSD18531Q5A" renamed to "CSD18531Q5A"
Component "CRCW040241K2FKED" renamed to "CRCW040241K2FKED"
Component "CRCW0603100RFKEA" renamed to "CRCW0603100RFKEA"
Component "CRCW060310R0FKEA" renamed to "CRCW060310R0FKEA"
Component "CRCW06031M18FKEA" renamed to "CRCW06031M18FKEA"
Component "CRCW060320K0FKEA" renamed to "CRCW060320K0FKEA"
Component "WSR39L000FEA" renamed to "WSR39L000FEA"
Component "CRCW040290K9FKED" renamed to "CRCW040290K9FKED"
Component "CRCW040232K4FKED" renamed to "CRCW040232K4FKED"
Component "CRCW0402249KFKED" renamed to "CRCW0402249KFKED"
Component "WB_GND" renamed to "WB_GND"
Component "CRCW060393K1FKEA" renamed to "CRCW060393K1FKEA"
Component "WB_CONTINUATION" renamed to "WB_CONTINUATION"
Component "WB_BATTERY" renamed to "WB_BATTERY"
Component "C5750X7R2A475M" renamed to "C5750X7R2A475M"
The Symbol WB_BLOCK_IO was missing a RefDes attribute, a refdes was created for the symbol.
The Symbol WB_BLOCK_IO was missing a Type attribute, a type was created for the symbol.
The Symbol WB_BLOCK_IO was missing a Value attribute, a value was created for the symbol.
The Symbol WB_STARTUP_VOLTAGE_SOURCE was missing a RefDes attribute, a refdes was created for the symbol.
The Symbol WB_STARTUP_VOLTAGE_SOURCE was missing a Type attribute, a type was created for the symbol.
The Symbol WB_STARTUP_VOLTAGE_SOURCE was missing a Value attribute, a value was created for the symbol.
The Symbol WB_SOURCE_RESISTOR was missing a RefDes attribute, a refdes was created for the symbol.
The Symbol WB_SOURCE_RESISTOR was missing a Type attribute, a type was created for the symbol.
The Symbol WB_SOURCE_RESISTOR was missing a Value attribute, a value was created for the symbol.
The Symbol WB_PRIM_STARTUP_VOLTAGE_SOURCE was missing a RefDes attribute, a refdes was created for the symbol.
The Symbol WB_PRIM_STARTUP_VOLTAGE_SOURCE was missing a Type attribute, a type was created for the symbol.
The Symbol WB_PRIM_STARTUP_VOLTAGE_SOURCE was missing a Value attribute, a value was created for the symbol.
The Symbol WB_CURRENT_PROBE was missing a RefDes attribute, a refdes was created for the symbol.
The Symbol WB_CURRENT_PROBE was missing a Type attribute, a type was created for the symbol.
The Symbol WB_CURRENT_PROBE was missing a Value attribute, a value was created for the symbol.
The Symbol WB_PWL_CURRENT_LOAD was missing a RefDes attribute, a refdes was created for the symbol.
The Symbol WB_PWL_CURRENT_LOAD was missing a Type attribute, a type was created for the symbol.
The Symbol WB_PWL_CURRENT_LOAD was missing a Value attribute, a value was created for the symbol.
The Symbol WB_PRIM_DC_VOLTAGE_SOURCE was missing a RefDes attribute, a refdes was created for the symbol.
The Symbol WB_PRIM_DC_VOLTAGE_SOURCE was missing a Type attribute, a type was created for the symbol.
The Symbol WB_PRIM_DC_VOLTAGE_SOURCE was missing a Value attribute, a value was created for the symbol.
The Symbol WB_ZERO_VOLT_SOURCE was missing a RefDes attribute, a refdes was created for the symbol.
The Symbol WB_ZERO_VOLT_SOURCE was missing a Type attribute, a type was created for the symbol.
The Symbol WB_ZERO_VOLT_SOURCE was missing a Value attribute, a value was created for the symbol.
The Symbol WB_PRIMITIVE_CAPACITOR was missing a RefDes attribute, a refdes was created for the symbol.
The Symbol WB_PRIMITIVE_CAPACITOR was missing a Type attribute, a type was created for the symbol.
The Symbol WB_PRIMITIVE_CAPACITOR was missing a Value attribute, a value was created for the symbol.
The Symbol WB_PRIM_PULSE_VOLTAGE_SOURCE was missing a RefDes attribute, a refdes was created for the symbol.
The Symbol WB_PRIM_PULSE_VOLTAGE_SOURCE was missing a Type attribute, a type was created for the symbol.
The Symbol WB_PRIM_PULSE_VOLTAGE_SOURCE was missing a Value attribute, a value was created for the symbol.
The Symbol WB_N_MOSFET was missing a RefDes attribute, a refdes was created for the symbol.
The Symbol WB_N_MOSFET was missing a Type attribute, a type was created for the symbol.
The Symbol WB_N_MOSFET was missing a Value attribute, a value was created for the symbol.
The Symbol WB_LM5175PWP was missing a RefDes attribute, a refdes was created for the symbol.
The Symbol WB_LM5175PWP was missing a Type attribute, a type was created for the symbol.
The Symbol WB_LM5175PWP was missing a Value attribute, a value was created for the symbol.
The Symbol WB_VOLTAGE_PROBE was missing a RefDes attribute, a refdes was created for the symbol.
The Symbol WB_VOLTAGE_PROBE was missing a Type attribute, a type was created for the symbol.
The Symbol WB_VOLTAGE_PROBE was missing a Value attribute, a value was created for the symbol.
The Symbol WB_LM5175_CDITH_BLOCK was missing a RefDes attribute, a refdes was created for the symbol.
The Symbol WB_LM5175_CDITH_BLOCK was missing a Type attribute, a type was created for the symbol.
The Symbol WB_LM5175_CDITH_BLOCK was missing a Value attribute, a value was created for the symbol.
The Symbol WB_LM5175_EXTVBIAS_BLOCK was missing a RefDes attribute, a refdes was created for the symbol.
The Symbol WB_LM5175_EXTVBIAS_BLOCK was missing a Type attribute, a type was created for the symbol.
The Symbol WB_LM5175_EXTVBIAS_BLOCK was missing a Value attribute, a value was created for the symbol.
The Symbol WB_LM5175_NO_CDITH_BLOCK was missing a RefDes attribute, a refdes was created for the symbol.
The Symbol WB_LM5175_NO_CDITH_BLOCK was missing a Type attribute, a type was created for the symbol.
The Symbol WB_LM5175_NO_CDITH_BLOCK was missing a Value attribute, a value was created for the symbol.
The Symbol WB_LM5175_NO_RISNS_BLOCK was missing a RefDes attribute, a refdes was created for the symbol.
The Symbol WB_LM5175_NO_RISNS_BLOCK was missing a Type attribute, a type was created for the symbol.
The Symbol WB_LM5175_NO_RISNS_BLOCK was missing a Value attribute, a value was created for the symbol.
The Symbol WB_LM5175_NO_RISNS_COMPONENTS_ was missing a RefDes attribute, a refdes was created for the symbol.
The Symbol WB_LM5175_NO_RISNS_COMPONENTS_ was missing a Type attribute, a type was created for the symbol.
The Symbol WB_LM5175_NO_RISNS_COMPONENTS_ was missing a Value attribute, a value was created for the symbol.
The Symbol WB_LM5175_NO_RMODE_BLOCK was missing a RefDes attribute, a refdes was created for the symbol.
The Symbol WB_LM5175_NO_RMODE_BLOCK was missing a Type attribute, a type was created for the symbol.
The Symbol WB_LM5175_NO_RMODE_BLOCK was missing a Value attribute, a value was created for the symbol.
The Symbol WB_LM5175_RISNS_BLOCK was missing a RefDes attribute, a refdes was created for the symbol.
The Symbol WB_LM5175_RISNS_BLOCK was missing a Type attribute, a type was created for the symbol.
The Symbol WB_LM5175_RISNS_BLOCK was missing a Value attribute, a value was created for the symbol.
The Symbol WB_LM5175_RISNS_COMPONENTS_BLO was missing a RefDes attribute, a refdes was created for the symbol.
The Symbol WB_LM5175_RISNS_COMPONENTS_BLO was missing a Type attribute, a type was created for the symbol.
The Symbol WB_LM5175_RISNS_COMPONENTS_BLO was missing a Value attribute, a value was created for the symbol.
The Symbol WB_LM5175_RMODE_BLOCK was missing a RefDes attribute, a refdes was created for the symbol.
The Symbol WB_LM5175_RMODE_BLOCK was missing a Type attribute, a type was created for the symbol.
The Symbol WB_LM5175_RMODE_BLOCK was missing a Value attribute, a value was created for the symbol.
The Symbol WB_LM5175_SYNC_BLOCK was missing a RefDes attribute, a refdes was created for the symbol.
The Symbol WB_LM5175_SYNC_BLOCK was missing a Type attribute, a type was created for the symbol.
The Symbol WB_LM5175_SYNC_BLOCK was missing a Value attribute, a value was created for the symbol.
The Symbol WB_LM5175_VOUTVBIAS_BLOCK was missing a RefDes attribute, a refdes was created for the symbol.
The Symbol WB_LM5175_VOUTVBIAS_BLOCK was missing a Type attribute, a type was created for the symbol.
The Symbol WB_LM5175_VOUTVBIAS_BLOCK was missing a Value attribute, a value was created for the symbol.
The Symbol WB_PWL_VOLTAGE_SOURCE was missing a RefDes attribute, a refdes was created for the symbol.
The Symbol WB_PWL_VOLTAGE_SOURCE was missing a Type attribute, a type was created for the symbol.
The Symbol WB_PWL_VOLTAGE_SOURCE was missing a Value attribute, a value was created for the symbol.
The Symbol WB_PRIM_PWL_VOLTAGE_SOURCE was missing a RefDes attribute, a refdes was created for the symbol.
The Symbol WB_PRIM_PWL_VOLTAGE_SOURCE was missing a Type attribute, a type was created for the symbol.
The Symbol WB_PRIM_PWL_VOLTAGE_SOURCE was missing a Value attribute, a value was created for the symbol.
The Symbol WB_LOAD_RESISTOR was missing a RefDes attribute, a refdes was created for the symbol.
The Symbol WB_LOAD_RESISTOR was missing a Type attribute, a type was created for the symbol.
The Symbol WB_LOAD_RESISTOR was missing a Value attribute, a value was created for the symbol.
The Symbol WB_PRIMITIVE_BATTERY was missing a RefDes attribute, a refdes was created for the symbol.
The Symbol WB_PRIMITIVE_BATTERY was missing a Type attribute, a type was created for the symbol.
The Symbol WB_PRIMITIVE_BATTERY was missing a Value attribute, a value was created for the symbol.

Ultra Librarian Gold 8.1.204 Process Report
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

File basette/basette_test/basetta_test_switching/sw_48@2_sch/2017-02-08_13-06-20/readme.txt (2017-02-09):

 

**********************************************************
*************  Important Instructions Follow  ************
**********************************************************
 
All files exported to: Z:\\47\\12\\4712046\\29\Eagle\2017-02-08_13-06-20\2017-02-08_13-06-20

**********************************************************
*****************Schematic Instructions  *******************
**********************************************************

To import your new Schematic file into Eagle:

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

**********************************************************
*******************  PCB Instructions  *******************
**********************************************************

To import your new BOARD file into Eagle:

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

**********************************************************
*******************  LIB Instructions  *******************
**********************************************************

To import your new library into Eagle:

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

For additional information, please visit this site:
http://www.accelerated-designs.com/help/Eagle_import.html

You may also find this video helpful:
http://youtu.be/5jGuWY-Yy3Q

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

Ultra Librarian Gold 8.1.204 Process Report

Message - Padstack "R10630430000200A" Shape(4) is a CIRCLE with no diameter.
Message - Padstack "RX26Y38D0T" Shape(4) is a CIRCLE with no diameter.
Message - Padstack "RX128Y31D0T" Shape(4) is a CIRCLE with no diameter.
Message - Padstack "RX14Y13D0T" Shape(4) is a CIRCLE with no diameter.
Message - Padstack "RX44Y57D0T" Shape(4) is a CIRCLE with no diameter.
Message - Padstack "RX44Y71D0T" Shape(4) is a CIRCLE with no diameter.
Message - Padstack "RX45Y213D0T" Shape(4) is a CIRCLE with no diameter.
Message - Padstack "R10470470000202A" Shape(4) is a CIRCLE with no diameter.
Message - Padstack "RX71Y81D0T" Shape(4) is a CIRCLE with no diameter.
Message - Padstack "RX94Y445D0T" Shape(4) is a CIRCLE with no diameter.
Message - Padstack "R10200250000209A" Shape(4) is a CIRCLE with no diameter.
Message - Padstack "RX31p5Y27p56D0T" Shape(4) is a CIRCLE with no diameter.
Message - Padstack "RX4p3Y4p56D0T" Shape(4) is a CIRCLE with no diameter.
Message - Padstack "RX22Y24D0T" Shape(4) is a CIRCLE with no diameter.
Message - Padstack "RX124Y220D0T" Shape(4) is a CIRCLE with no diameter.
Message - Padstack "O1014067000P0204" Shape(4) is a CIRCLE with no diameter.
Message - Padstack "R1122204000P0204" Shape(4) is a CIRCLE with no diameter.
Message - Component "C3216X7R2A105M160AA" attribute "Datasheet URL" references text style "" that is not in the database.
The default pattern text style "H50s3" was substituted.
Message - Component "C3216X7R2A105M160AA" attribute "Cap" references text style "" that is not in the database.
The default pattern text style "H50s3" was substituted.
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

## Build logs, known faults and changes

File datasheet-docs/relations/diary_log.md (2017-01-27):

## Diary log of the design process

### Agilent schematics

The schematics that Mr. Tombola gave us came from the incredibly good Agilent E361x series. After a little research I was able to find the maintenance manual, with the schematics and a bill of material.

This is the schematic

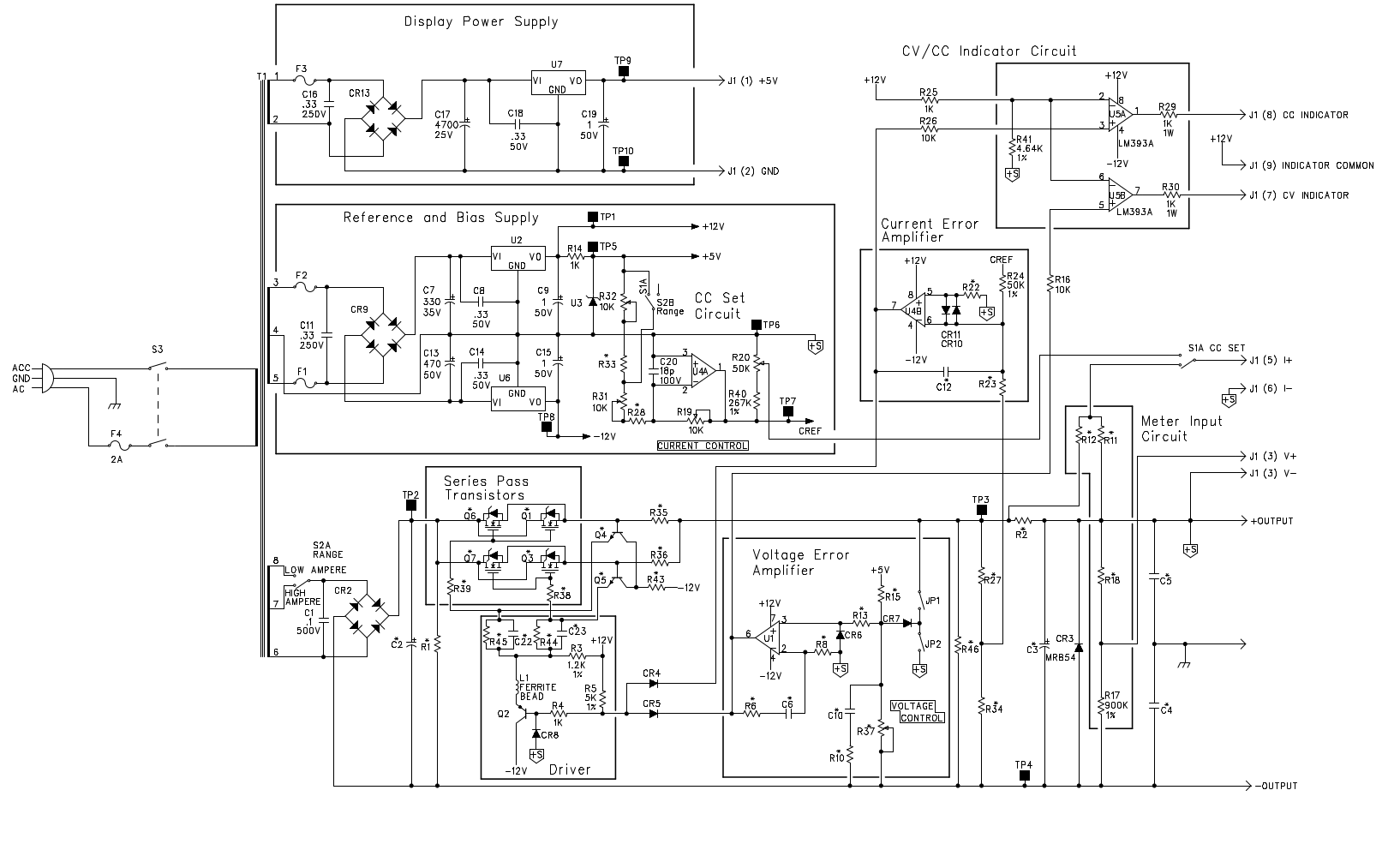
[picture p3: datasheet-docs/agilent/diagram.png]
diagram


As you can see it's divided into small sections. Here is a brief the behavior of each section.

* *Reference and Bias supply* hosts not only the reference and bias supply, but also the current reference generator, which will be discussed later. The reference supply is powered by a separate tap on the main transformer. The current from this tap is rectified, filtered and then fed through some linear regulators, (78xx/79xx). The outputs from these regulators are the logic power rails

  ***An important note*** the ground of this tap is not earth, but is connected to the high rail of the output power rail. This means that with respect to the earth the logic supply swings according to the changes in the output voltage. The aforementioned configuration gives a lot of benefits, mainly it removes the necessity of using special opamps that can work on the full power output ranges. The big disadvantage is the need for another tap in the transformer.

* *Current & Voltage Error Amplifier*s This is the core of the schematic, those two circuits are the ones that implement all of the regulation of our PSU.

  * *Current error amplifier* This is an inverting amplifier, the circuit must be studied together with the opamp circuit in the reference and bias supply. This last circuit basically gives the error amplifier a reference. The current limit is set by using the potentiometer (R16) 
  * *Voltage error amplifier* This also is an inverting amplifier. The reference in this case is generated via a voltage divider controlled by a variable resistor. This reference will set the voltage when in Constant Voltage mode.

* *Series Pass Transistor & Driver* These two elements are very intuitive. The first one is the driving element, while the second is the gate driver, in order not to pull current from the Error Amplifier circuits.

* *CV/CC Indicator Circuit* Well, not much to say here. This part is used just to light some LEDs on the front panel according to the mode in which the PSU is working.

The modifications that we have applied can be described according to their location.

Regarding the Voltage error amplifier, we opted to swap the fixed +5V reference with a DAC, in order to be able to control it with a uC. This modification may seem like an easy one but it's not and it will be described later.

On the Current Error Amplifier side, the solution was similar to the one done before, but we had to take into account the behavior of the current reference generator.

On the pass element side, we swapped the mosfet array for a single more powerful one. The rest of this stage remained mostly unchanged.

**How we will carry out the tests**

In order to test the Linear stage of the PSU Nicolo came up with a great idea. Instead of routing the whole board equipped with the DACs and the uC, we could route a stripped version of the original Agilent design so that we could swap in the full analog control circuit for the digital one. This will hopefully improve our testing stage, making it easier, because we could choose whether or not to put in the digital circuit which is probably the most complicated part.

### The digital control circuit

I wanted to go full digital, using DSP and some control routines, but Mr. Tombola advised me against this design decision because of its complexity.

So we settled for a PIC uC and some DACs. The schematic of the digital part can be seen here. 

test_digitale.sch

The first thing that can be seen is the super skookum PIC. This PIC has a lot of cool features, like an internal HS Clock Generator (*32 MHz*), 10 bit ADC, SPI & UART module.

The most interesting part about this thing in my opinion is the internal oscillator. No need to bother with quartz resonant circuits or with very expensive oscillators, everything is inside the chip. As a side note, in one of the errdata a particular procedure is mentioned that <u>must</u> be followed when configuring the HS Oscillator.

We decided to leverage the uC capabilities as much as we could. To do so, we decided to use the analog inputs  to sense the current and the voltage, we connected two GPIO to the CV/CC indicators and we added two LEDs, just to make sure that the thing shines a bit.

Setting aside the less useful parts, the main focus was to be able to generate a variable DC voltage. We could have used the integrated DAC on the PIC, but because of its poor resolution we decided to opt for some external DAC, which were also made by MicroChip.  These DACs are controlled using the I2C protocol, the only caveat is that the address is not set via some pins on the uC, but it's burned directly on to the silicon chip. This means that the address must be chosen when ordering the parts, so a lot of attention must be paid to the last digits of the serial number.

I plan to write the code for this chip using MCC, which is a plug-in of MPLABXIDE, this software is made by MicroChip and can provide some neat ways of configuring the device. The whole device configuration is done via a drag'n drop graphical interface. It also provides some libraries that can help us using the device peripheries.

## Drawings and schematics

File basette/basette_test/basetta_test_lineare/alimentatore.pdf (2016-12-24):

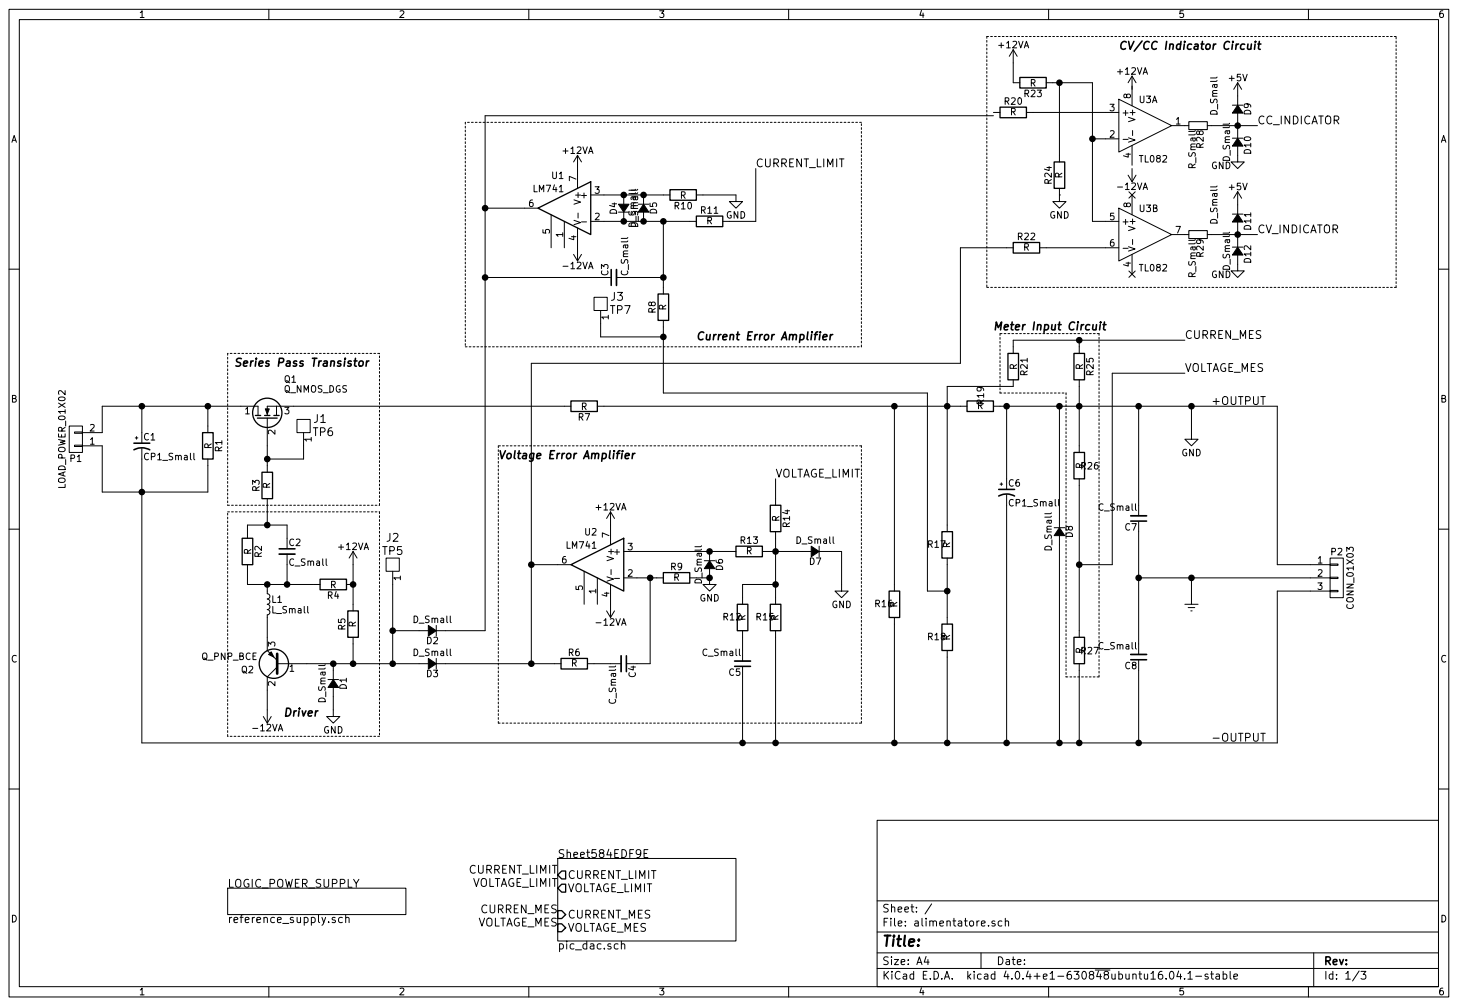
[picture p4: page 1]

Id: 1/3 Title: File: alimentatore.sch Sheet: / Sheet584EDF9E
CURRENT_LIMIT
VOLTAGE_LIMIT

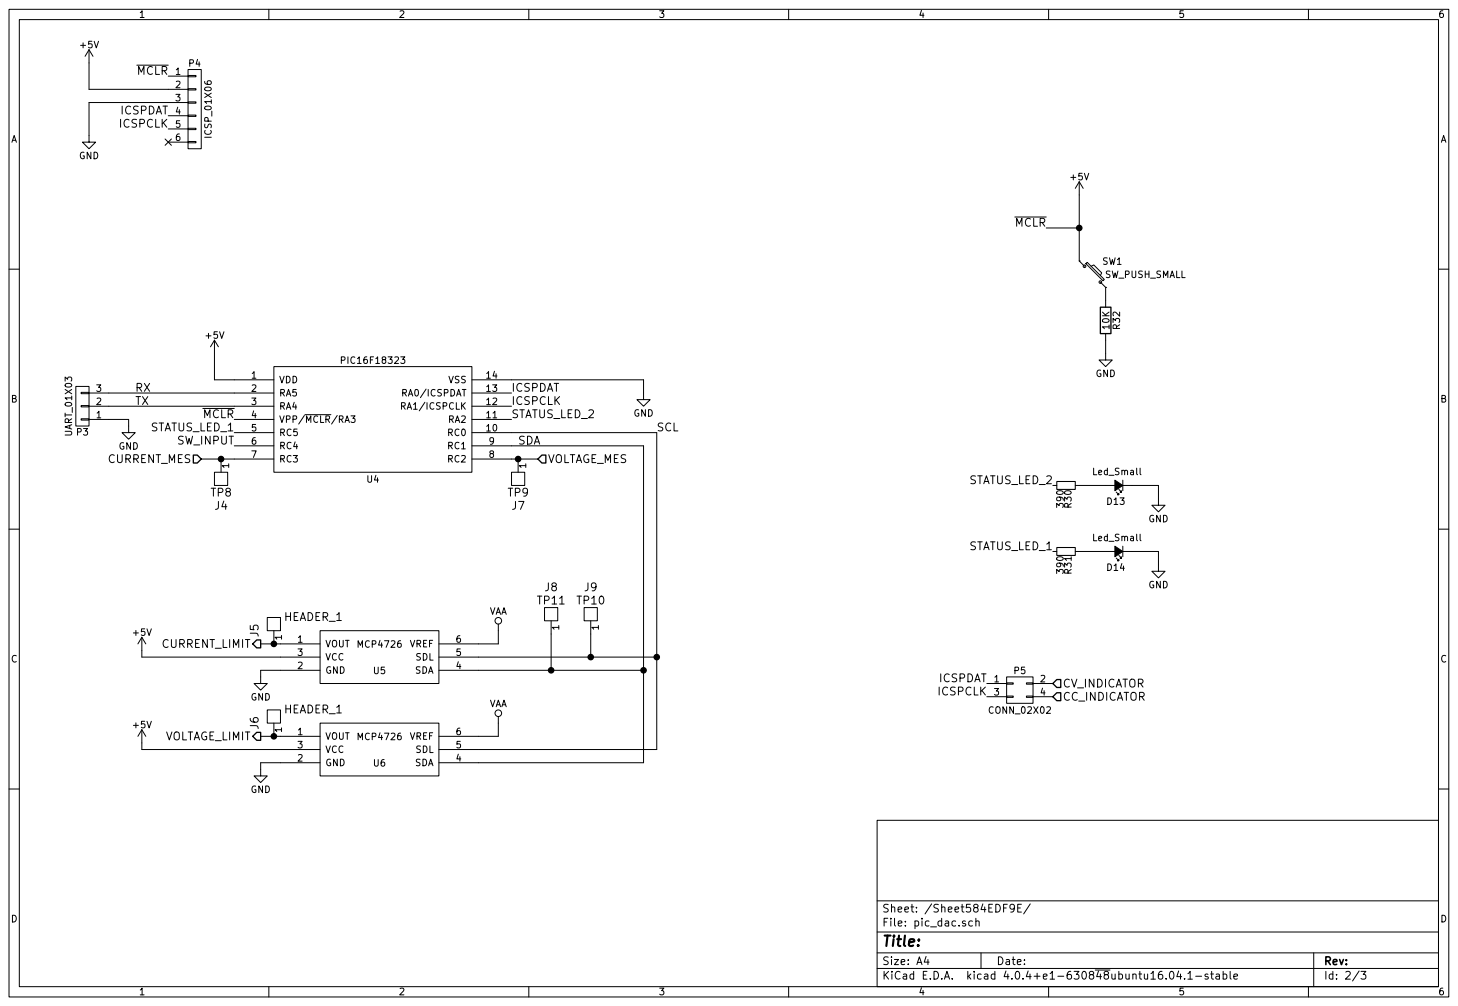
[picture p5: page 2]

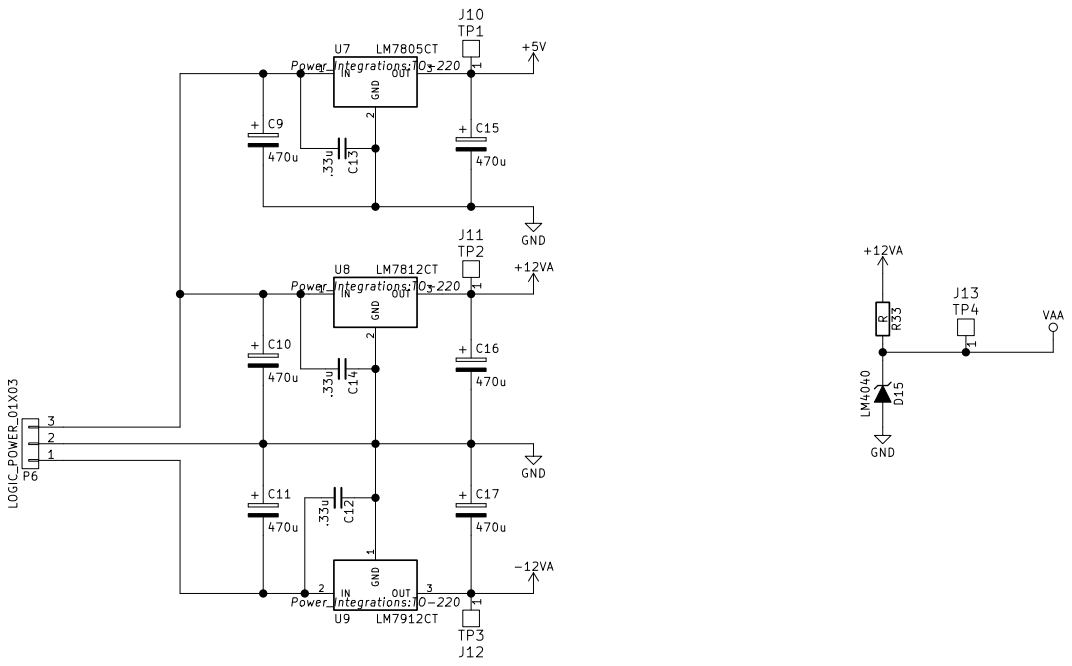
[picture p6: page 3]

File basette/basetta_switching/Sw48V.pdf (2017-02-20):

## WEBENCH ® Design Report

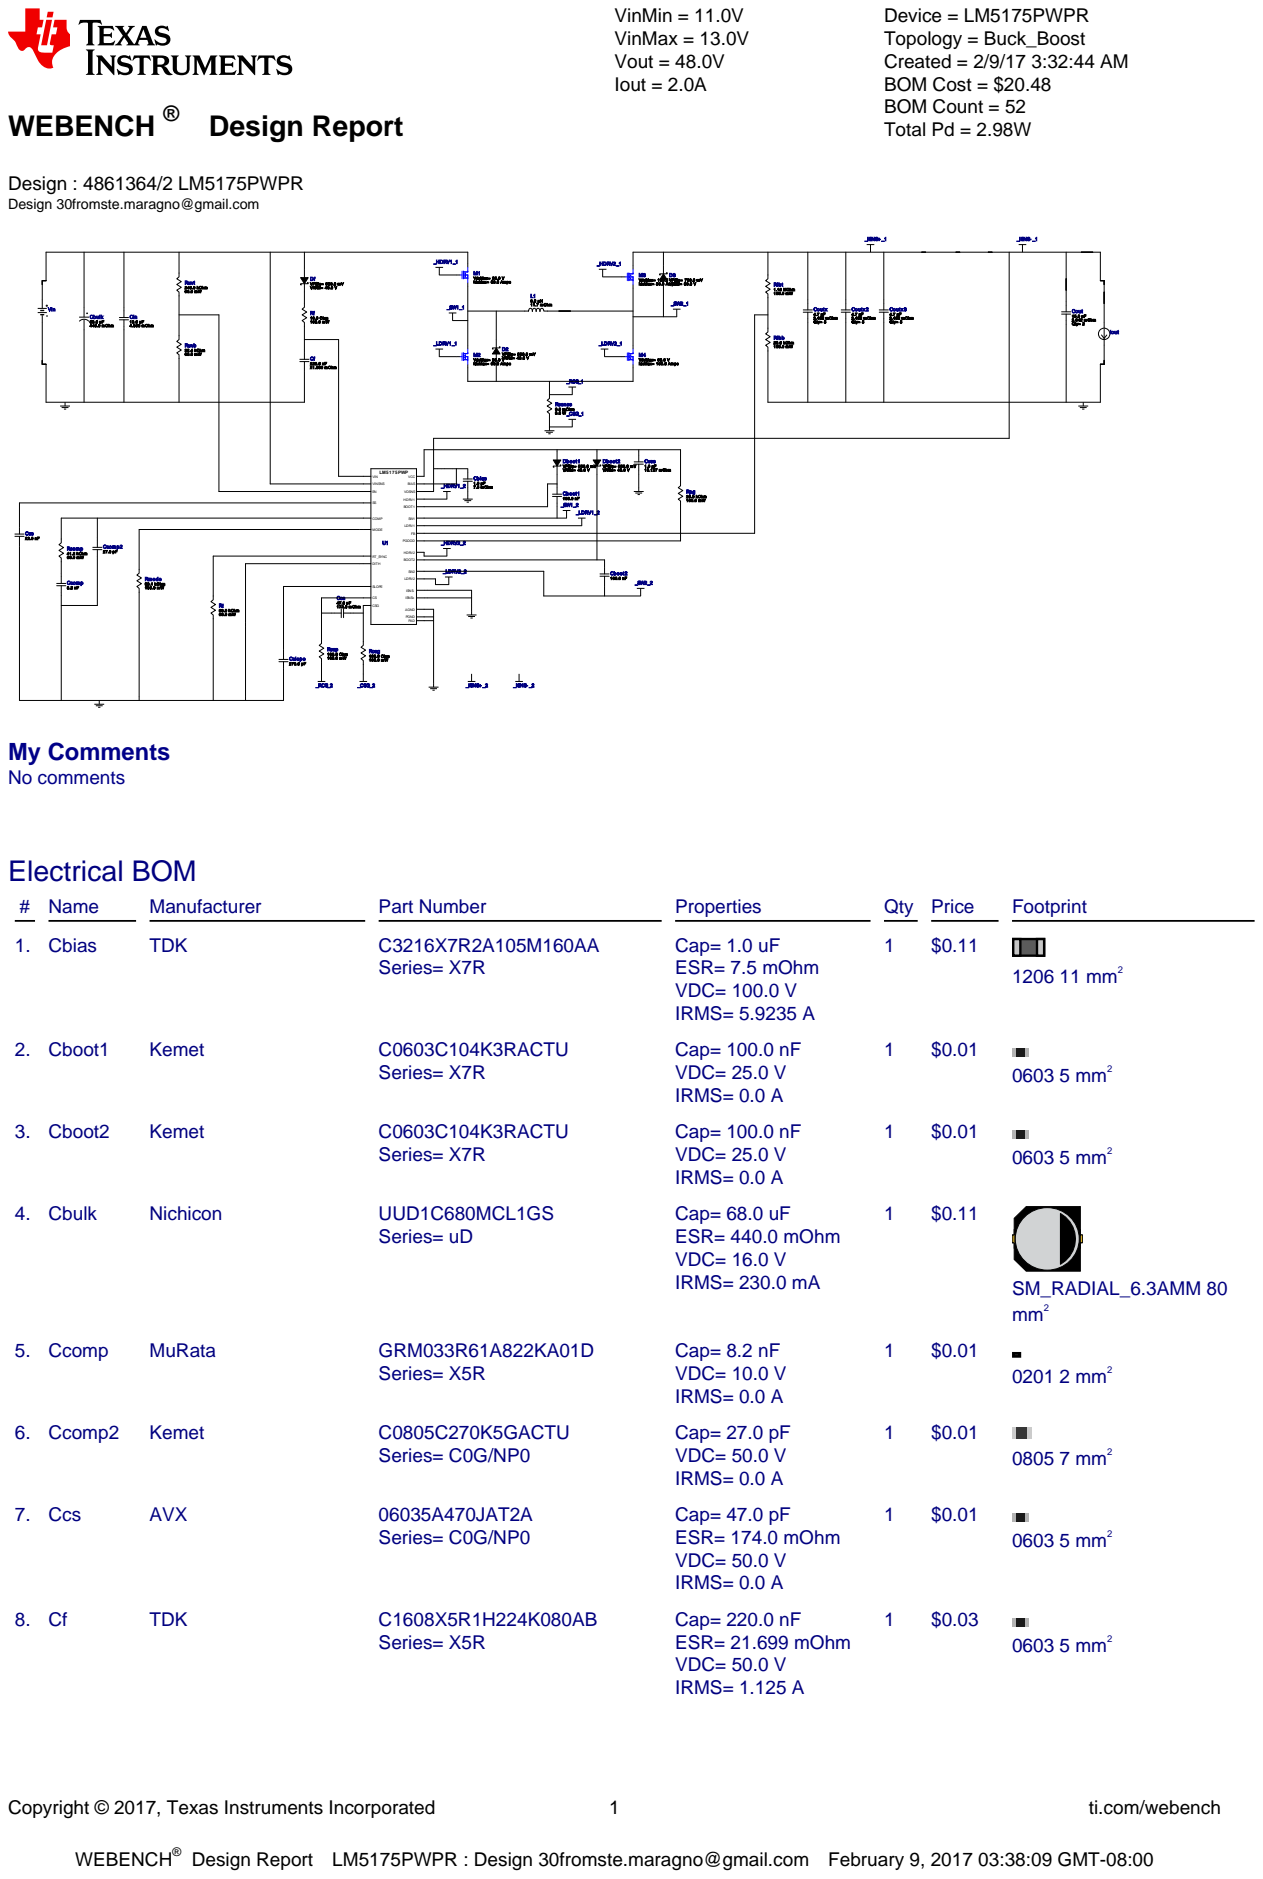
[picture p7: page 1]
Copyright © 2017, Texas Instruments Incorporated; ti.com/webench; WEBENCH®; VinMin = 11.0V VinMax = 13.0V Vout = 48.0V Iout = 2.0A; Device = LM5175PWPR Topology = Buck_Boost Created = 2/9/17 3:32:44 AM BOM Cost = $20.48 BOM Count = 52 Total Pd = 2.98W; Cbias 1.0 µF; 7.5 mOhm; Cboot1; Cboot2 100.0 nF; Cbulk 68.0 µF 440.0 mOhm; Ccomp 8.2 nF; Ccomp2 27.0 pF; Ccs 47.0 pF 174.0 mOhm; 21.699 mOhm; Cin 10.0 µF 4.366 mOhm; Cout 15.0 µF; 2.642 mOhm Qty= 2; Coutx 4.7 µF 2.482 mOhm Qty= 5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

Design : 4861364/2 LM5175PWPR
Design 30fromste.maragno@gmail.com

Dboot1

VRRM= 40.0 V

Design Report LM5175PWPR : Design 30fromste.maragno@gmail.com February 9, 2017 03:38:09 GMT-08:00

Design

Copyright © 2017, Texas Instruments Incorporated | 2 | ti.com/webench
# Name | Manufacturer | Part Number | Properties | Qty Price | Footprint

9. Cin | MuRata | GRM31CR71E106KA12L (http://psearch.en.murata.com/capacitor/result/smd/?status%3Dall%26pid%3DGRM31CR71E106KA12L) Series= X7R | Cap= 10.0 uF ESR= 4.366 mOhm VDC= 25.0 V IRMS= 2.8022 A
1 | $0.05
| | | | | 1206_190 11 mm²
10. Cout | TDK | CGA9P3X7S2A156M250KB (https://product.tdk.com/en/search/capacitor/ceramic/mlcc/info?part%5Fno%3DCGA9P3X7S2A156M250KB) Series= X7S | Cap= 15.0 uF ESR= 2.642 mOhm VDC= 100.0 V IRMS= 5.6162 A
2 | $1.24
| | | | | 2220_280 54 mm²
11. Coutx | TDK | C5750X7R2A475M (http://www.tdk.co.jp/tefe02/e412%5Fc.pdf) Series= X7R | Cap= 4.7 uF ESR= 2.482 mOhm VDC= 100.0 V IRMS= 0.0 A
5 | $0.67
| | | | | 2220 54 mm²
12. Coutx2 | TDK | C5750X7R2A475M (http://www.tdk.co.jp/tefe02/e412%5Fc.pdf) Series= X7R | Cap= 4.7 uF ESR= 2.482 mOhm VDC= 100.0 V IRMS= 0.0 A
5 | $0.67
| | | | | 2220 54 mm²
13. Coutx3 | TDK | C5750X7R2A475M (http://www.tdk.co.jp/tefe02/e412%5Fc.pdf) Series= X7R | Cap= 4.7 uF ESR= 2.482 mOhm VDC= 100.0 V IRMS= 0.0 A
5 | $0.67
| | | | | 2220 54 mm²
14. Cslope | Yageo America | CC0603JRNPO9BN271 (http://www.yageo.com/documents/recent/UPY%2DGP%5FNP0%5F16V%2Dto%2D50V%5F10.pdf) Series= C0G/NP0 | Cap= 270.0 pF VDC= 50.0 V IRMS= 0.0 A
1 | $0.01
| | | | | 0603 5 mm²
15. Css | Kemet | C0603C223K3RACTU (http://www.kemet.com/kemet/web/homepage/kechome.nsf/vapubfiles/F3102%5FY5V.pdf/%24file/F3102%5FY5V.pdf) Series= X7R | Cap= 22.0 nF VDC= 25.0 V IRMS= 0.0 A
1 | $0.01
| | | | | 0603 5 mm²
16. Cvcc | MuRata | GRM188R61C105KA93D (http://psearch.en.murata.com/capacitor/result/smd/?status%3Dall%26pid%3DGRM188R61C105KA93D) Series= X5R | Cap= 1.0 uF ESR= 10.127 mOhm VDC= 16.0 V IRMS= 994.63 mA
1 | $0.01
| | | | | 0603 5 mm²
17. D2 | Fairchild Semiconductor SS24FL | VF@Io= 550.0 mV
VRRM= 40.0 V

1 $0.07
SOD-123F 12 mm²
18. D3 | Diodes Inc. | B260-13-F (http://www.diodes.com/datasheets/ds13004.pdf) | VF@Io= 700.0 mV VRRM= 60.0 V
1 | $0.09

SMB 44 mm²
19. Dboot1 | Fairchild Semiconductor SS24FL | VF@Io= 550.0 mV
| | | VRRM= 40.0 V
1 | $0.07
SOD-123F 12 mm²
20. Dboot2 | Fairchild Semiconductor SS24FL | VF@Io= 550.0 mV
| | | VRRM= 40.0 V
1 | $0.07
SOD-123F 12 mm²
21. Df | Fairchild Semiconductor SS24FL | VF@Io= 550.0 mV
| | | VRRM= 40.0 V
1 | $0.07
SOD-123F 12 mm²
22. L1 | Coilcraft | XAL1010-822MEB (http://www.coilcraft.com/pdfs/xal1010.pdf) | L= 8.2 µH DCR= 11.7 mOhm
1 | $1.71

XAL1010 160 mm²
23. M1 | Texas Instruments | CSD16323Q3 (http://focus.ti.com/lit/ds/symlink/csd16323q3.pdf) | VdsMax= 25.0 V IdsMax= 60.0 Amps
1 | $0.36

DQG0008A 18 mm²
24. M2 | Texas Instruments | CSD16323Q3 (http://focus.ti.com/lit/ds/symlink/csd16323q3.pdf) | VdsMax= 25.0 V IdsMax= 60.0 Amps
1 | $0.36

DQG0008A 18 mm²
25. M3 | Texas Instruments | CSD19534Q5A (http://www.ti.com/lit/ds/symlink/csd19534q5a.pdf) | VdsMax= 100.0 V IdsMax= 50.0 Amps
1 | $0.34

TRANS_NexFET_Q5A 55
mm²
26. M4 | Texas Instruments | CSD18531Q5A (http://www.ti.com/lit/ds/symlink/csd18531q5a.pdf) | VdsMax= 60.0 V IdsMax= 100.0 Amps
1 | $0.58

TRANS_NexFET_Q5A 55
mm²

Copyright © 2017, Texas Instruments Incorporated | 3 | ti.com/webench
# Name | Manufacturer | Part Number | Properties | Qty Price | Footprint

27. Rcomp | Vishay-Dale | CRCW040241K2FKED (http://www.vishay.com/docs/20035/dcrcwe3.pdf) Series= CRCW..e3 | Res= 41.2 kOhm Power= 63.0 mW Tolerance= 1.0%
1 | $0.01
| | | | | 0402 3 mm²
28. Rcsg | Vishay-Dale | CRCW0603100RFKEA (http://www.vishay.com/docs/20035/dcrcwe3.pdf) Series= CRCW..e3 | Res= 100.0 Ohm Power= 100.0 mW Tolerance= 1.0%
1 | $0.01
| | | | | 0603 5 mm²
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

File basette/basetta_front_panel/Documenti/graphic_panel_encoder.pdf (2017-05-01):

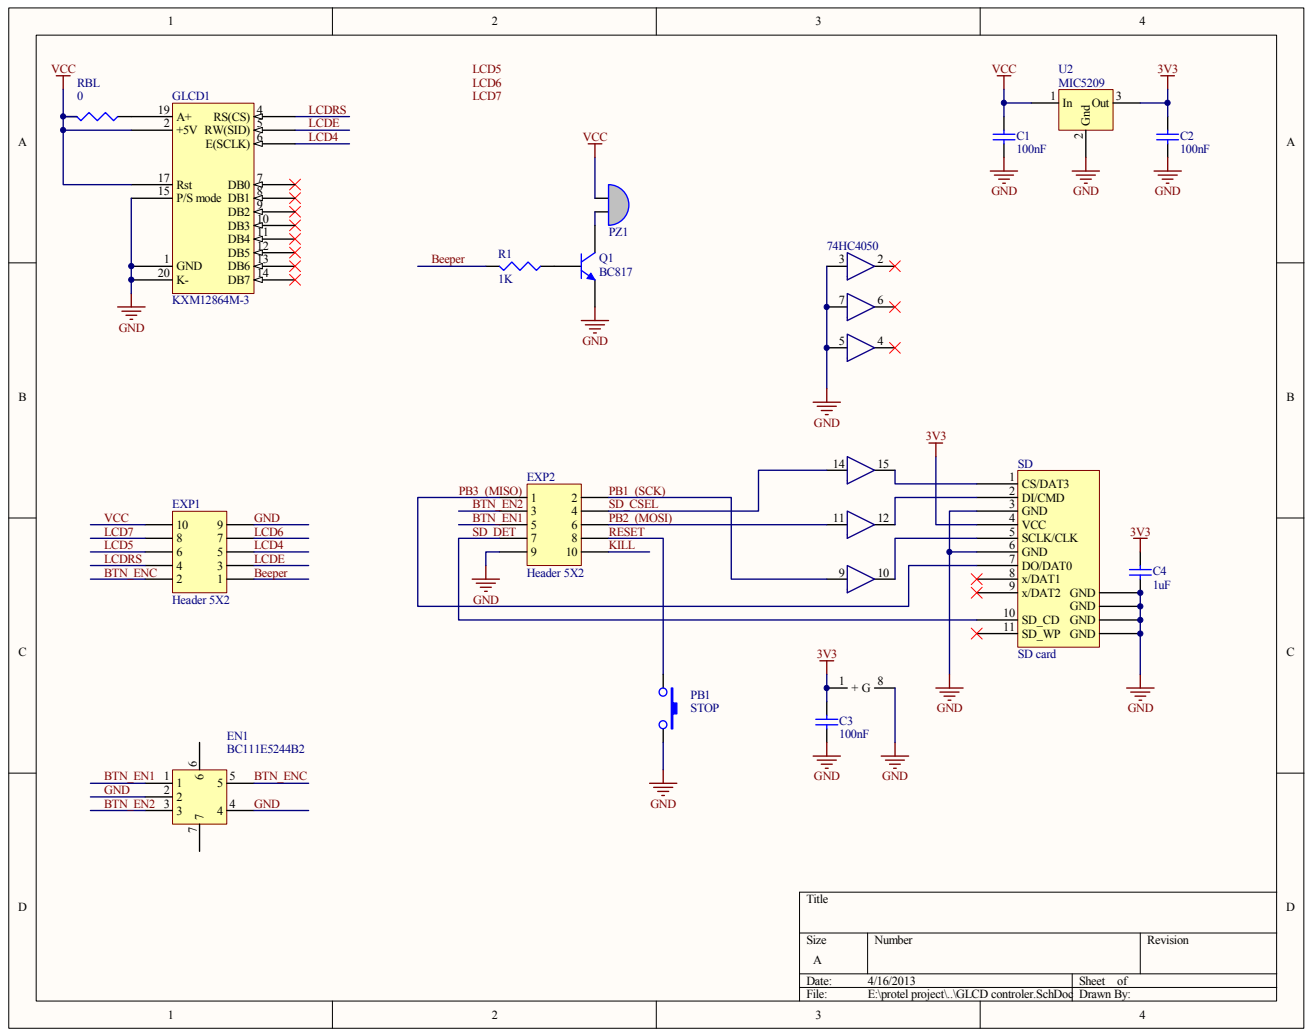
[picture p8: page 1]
Title; Size; Number; Revision; Date:; Sheet of; File:; E:\protel project\..\GLCD controler.SchDoc; Drawn By:; EXP1; Header 5X2; VCC LCD7 LCD5 LCDRS; GND LCD6 LCD4 LCDE Beeper; LCD4; LCD5 LCD6 LCD7; LCDE; LCDRS; GND; VCC; BTN_ENC; EXP2; BTN_EN2 BTN_EN1 SD_DET; SD_CSEL; PB3_(MISO); PB1_(SCK); PB2_(MOSI) RESET KILL; CS/DAT3 1 DI/CMD 2 GND 3 VCC 4 SCLK/CLK 5 GND 6 DO/DAT0 7 x/DAT1 8 x/DAT2 9; GND GND GND GND; SD card; Gnd; Out 3; U2 MIC5209; PB1 STOP; BTN_EN1; BTN_EN2; RS(CS) 4 RW(SID) 5 E(SCLK) 6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

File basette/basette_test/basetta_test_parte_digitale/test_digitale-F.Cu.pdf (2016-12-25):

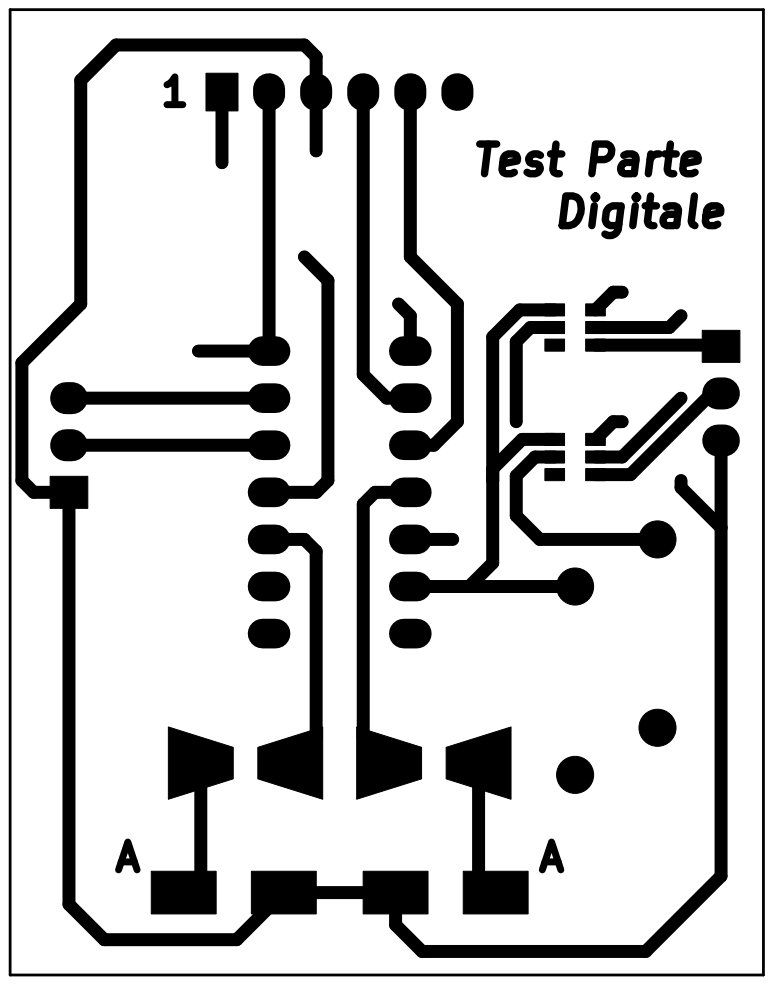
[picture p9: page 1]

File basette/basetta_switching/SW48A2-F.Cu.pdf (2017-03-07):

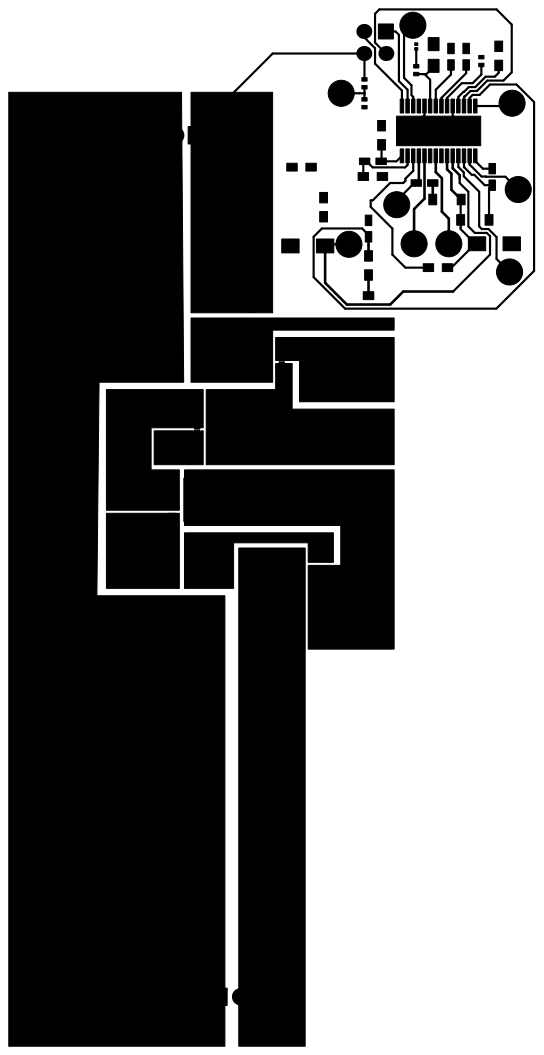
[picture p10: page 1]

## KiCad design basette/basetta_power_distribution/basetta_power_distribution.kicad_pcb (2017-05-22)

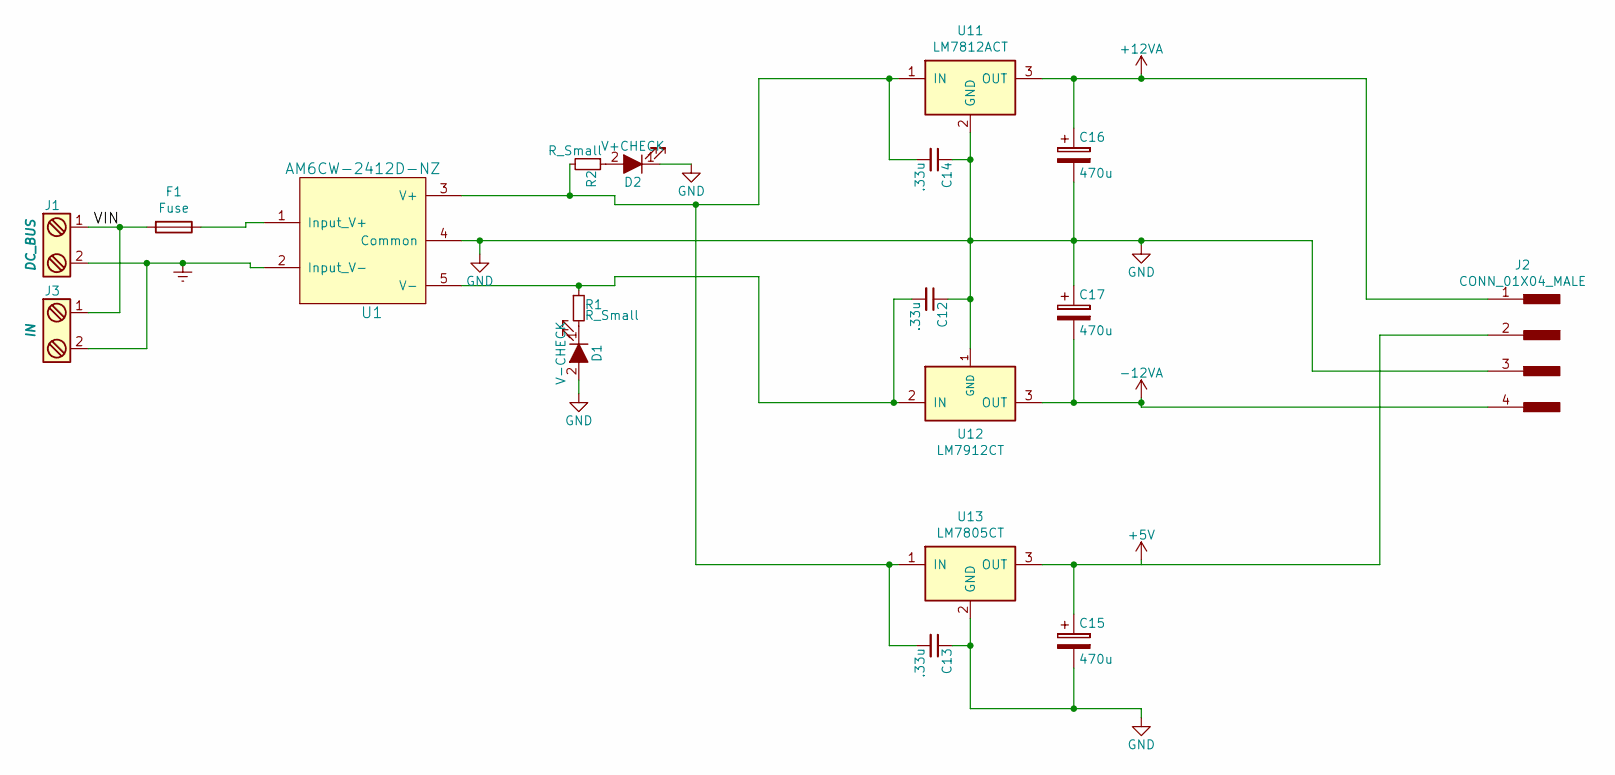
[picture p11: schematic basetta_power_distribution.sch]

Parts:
C12, C13, C14: .33u; C_Disc_D7.5mm_W5.0mm_P5.00mm; Voltage 50V
C15, C16, C17: 470u; CP_Radial_D8.0mm_P3.50mm; Voltage 50V
D1: V-CHECK; D_1206
D2: V+CHECK; D_1206
F1: Fuse; R_1210_HandSoldering
J1: DC_BUS; TerminalBlock_Pheonix_MPT-2.54mm_2pol
J2: CONN_01X04_MALE; Pin_Header_Straight_1x04_Pitch2.54mm
J3: IN; TerminalBlock_Pheonix_MPT-2.54mm_2pol
R1, R2: R_Small; R_1206_HandSoldering
U1: AM6CW-2412D-NZ; AM4CW-NZ
U11: LM7812ACT; TO-220_Vertical
U12: LM7912CT; TO-220_Vertical
U13: LM7805CT; TO-220_Vertical

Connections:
+12VA: C16.1, J2.1, U11.3 (OUT)
-12VA: C17.2, J2.4, U12.3 (OUT)
/VIN: F1.2, J1.1, J3.1
Earth: J1.2, J3.2, U1.2 (Input_V-)
GND: C12.1, C13.1, C14.1, C15.2, C16.2, C17.1, D1.2 (A), D2.1 (K), J2.3, U1.4 (Common), U11.2 (GND), U12.1 (GND), U13.2 (GND)
unnamed: C12.2, R1.1, U1.5 (V-), U12.2 (IN)
unnamed: C13.2, C14.2, R2.2, U1.3 (V+), U11.1 (IN), U13.1 (IN)
unnamed: C15.1, J2.2, U13.3 (OUT)
unnamed: D1.1 (K), R1.2
unnamed: D2.2 (A), R2.1
unnamed: F1.1, U1.1 (Input_V+)

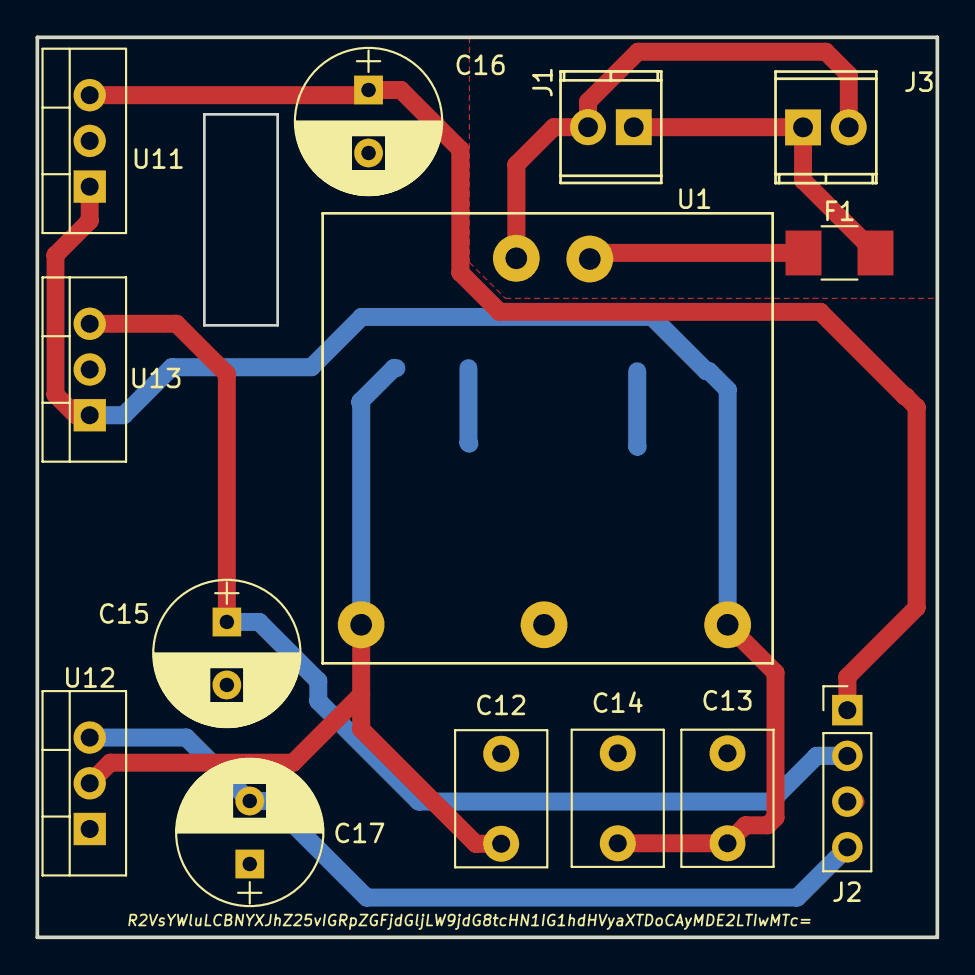
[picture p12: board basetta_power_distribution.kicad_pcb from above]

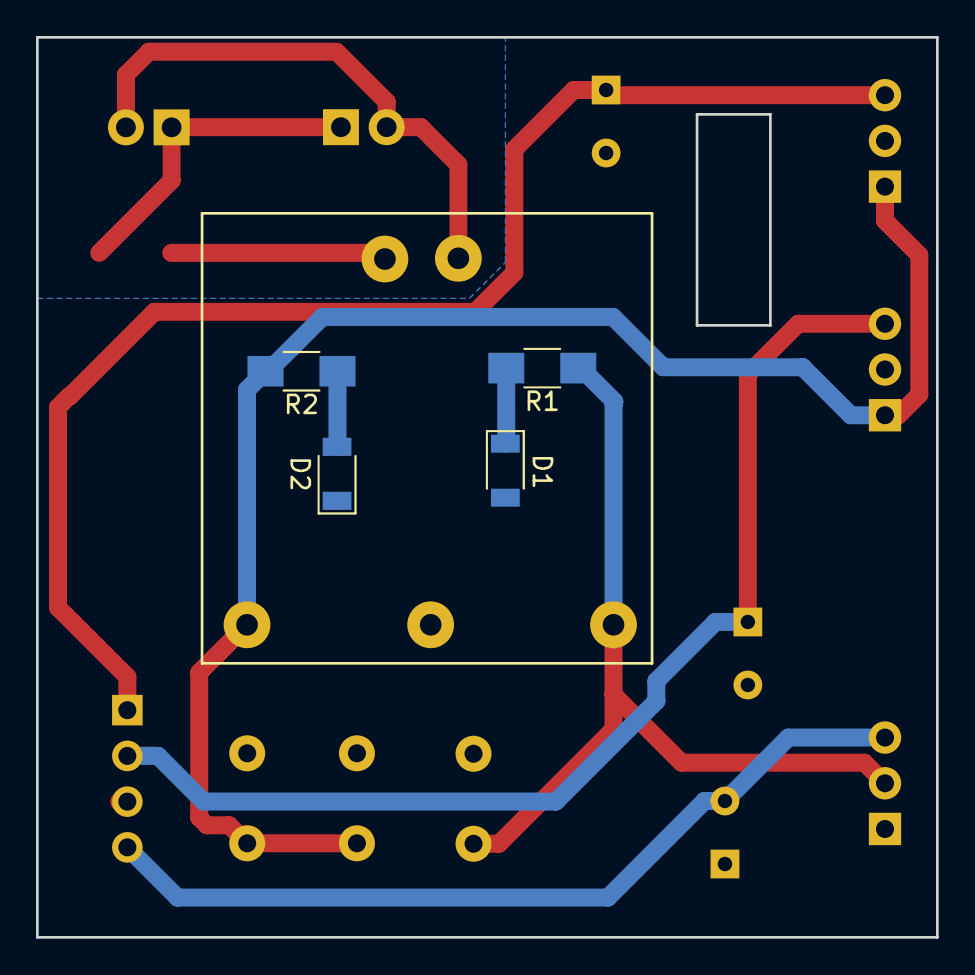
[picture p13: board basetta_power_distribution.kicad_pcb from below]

Board: 2 copper layers, 50.0 x 50.0 mm, 18 parts (4 on the bottom side), 11 nets.

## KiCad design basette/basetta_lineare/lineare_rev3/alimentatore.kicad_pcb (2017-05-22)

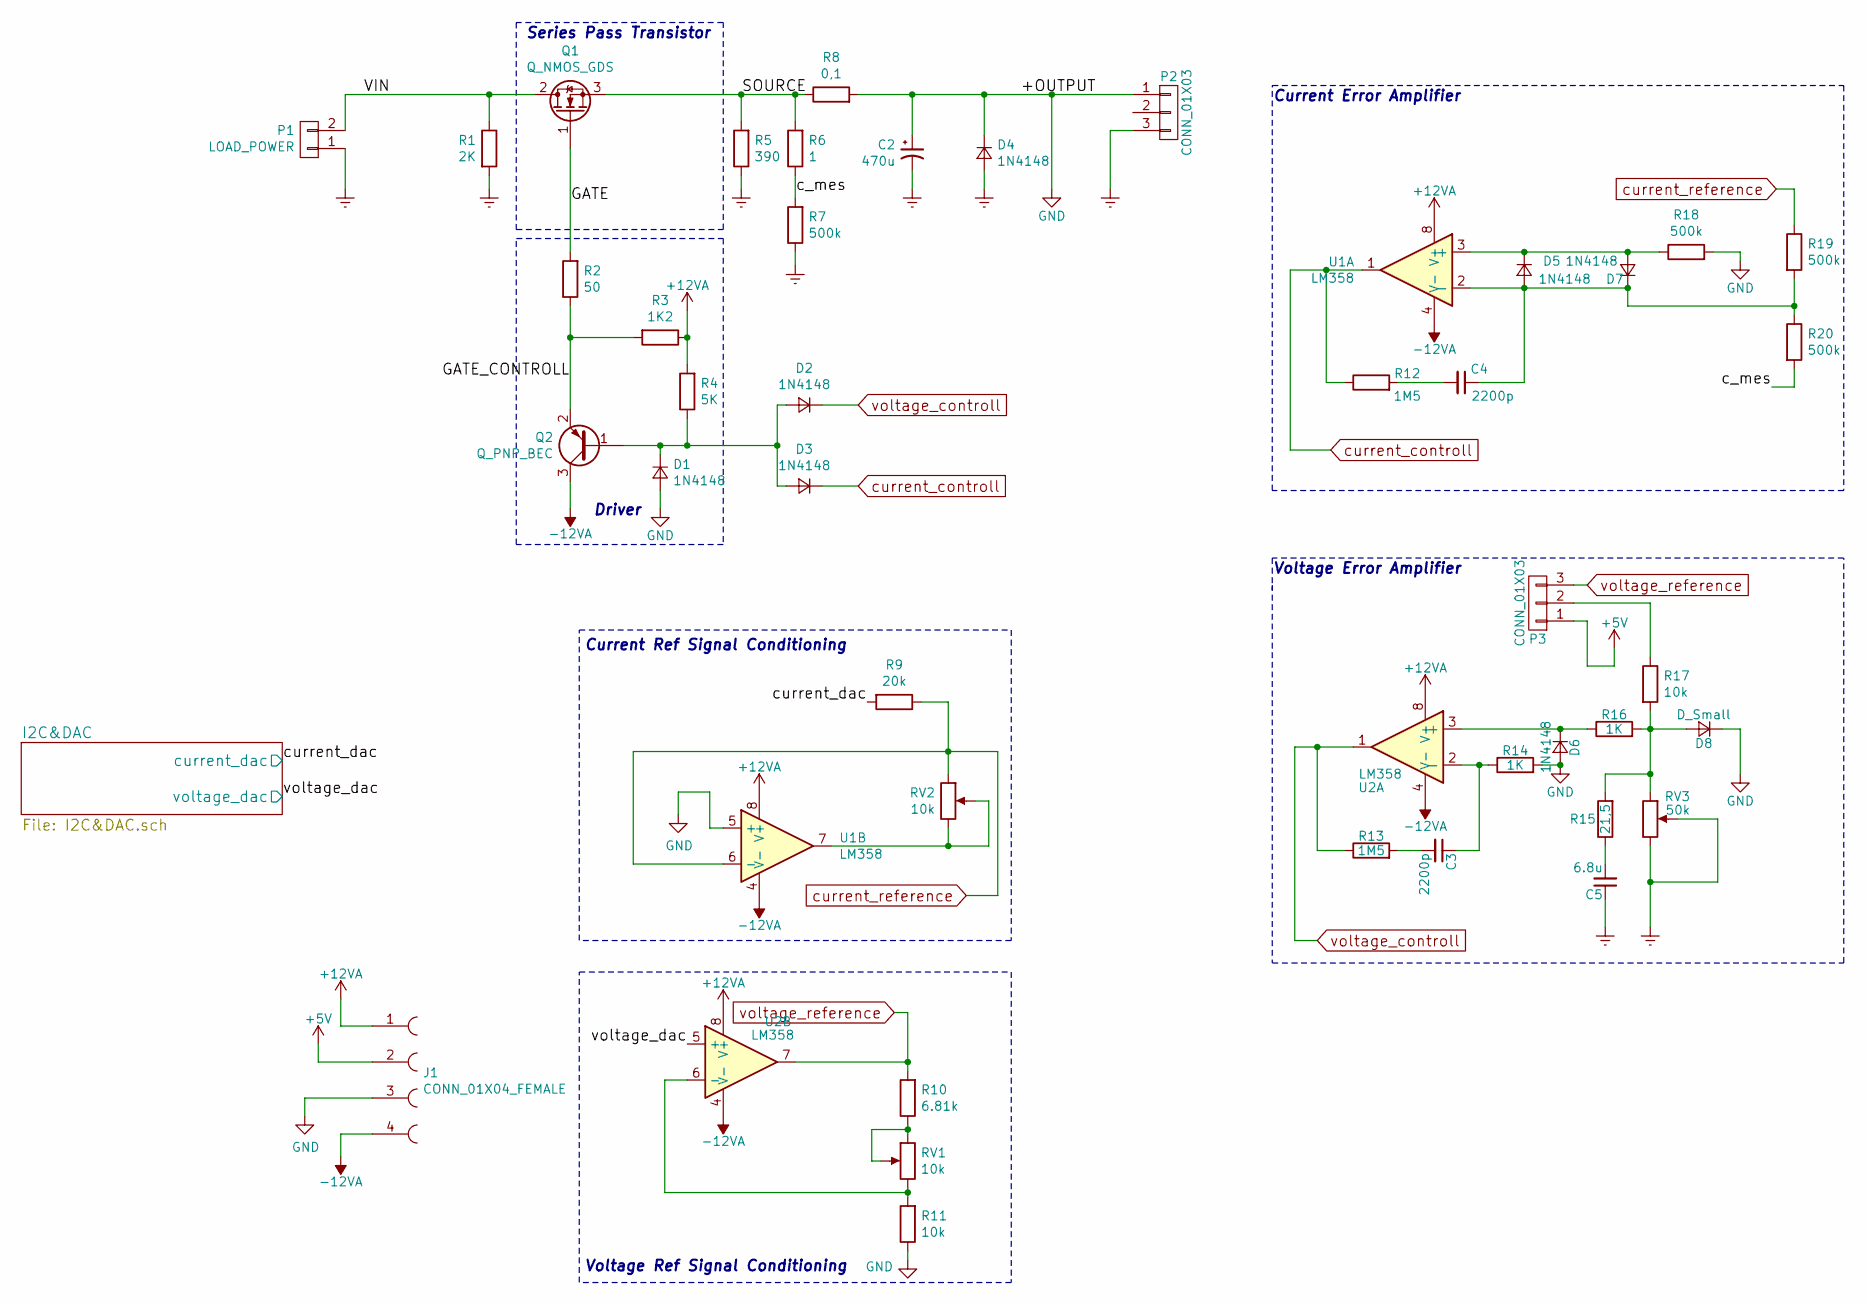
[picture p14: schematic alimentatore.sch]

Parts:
C2: 470u; CP_Radial_D14.0mm_P5.00mm; Voltage 50V
C3, C4: 2200p; C_0805; Voltage 50V
C5: 6.8u; C_0805; Voltage 35V
D1, D2, D3, D4, D5, D6, D7: 1N4148; D_0603
D8: D_Small; D_0603
J1: CONN_01X04_FEMALE; Pin_Header_Straight_1x04_Pitch2.54mm
P1: LOAD_POWER; TerminalBlock_Pheonix_MPT-2.54mm_2pol
P2: CONN_01X03; TerminalBlock_Pheonix_MPT-2.54mm_3pol
P3: CONN_01X03; Pin_Header_Straight_1x03_Pitch2.54mm
Q1: Q_NMOS_GDS; TO-220_Vertical
Q2: Q_PNP_BEC; SOT-23
R1: 2K; R_1206_HandSoldering
R2: 50; R_1206_HandSoldering
R3: 1K2; R_1206_HandSoldering
R4: 5K; R_1206_HandSoldering
R5: 390; R_1206_HandSoldering
R6: 1; R_1206_HandSoldering
R7, R18, R19, R20: 500k; R_1206_HandSoldering
R8: 0,1; R_2512_HandSoldering
R9: 20k; R_1206_HandSoldering
R10: 6.81k; R_1206_HandSoldering
R11, R17: 10k; R_1206_HandSoldering
R12, R13: 1M5; R_1206_HandSoldering
R14, R16: 1K; R_1206_HandSoldering
R15: 21,5; R_1206_HandSoldering
RV1, RV2: 10k; SR_Passive
RV3: 50k; SR_Passive
U1, U2: LM358; SO-8

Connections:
+12VA: J1.1, R3.1, R4.2, U1.8 (V+), U2.8 (V+)
-12VA: J1.4, Q2.3 (C), U1.4 (V-), U2.4 (V-)
/GATE: Q1.1 (G), R2.2
/GATE_CONTROLL: Q2.2 (E), R2.1, R3.2
/SOURCE: Q1.3 (S), R5.2, R6.2, R8.1
/VIN: P1.2, Q1.2 (D), R1.1
/c_mes: R6.1, R7.2, R20.2
Earth: C2.2, C5.1, D4.2 (A), P1.1, P2.3, R1.2, R5.1, R7.1, RV3.2, RV3.3
unnamed: C3.1, R14.1, U2.2 (-)
unnamed: C3.2, R13.2
unnamed: C4.1, D5.2 (A), D7.1 (K), R19.2, R20.1, U1.2 (-)
unnamed: C4.2, R12.2
unnamed: C5.2, R15.1
unnamed: D1.1 (K), D2.2 (A), D3.2 (A), Q2.1 (B), R4.1
unnamed: D5.1 (K), D7.2 (A), R18.1, U1.3 (+)
unnamed: D6.1 (K), R16.1, U2.3 (+)
unnamed: D8.2 (A), R15.2, R16.2, R17.2, RV3.1
unnamed: P3.2, R17.1
unnamed: R10.1, RV1.1, RV1.2
unnamed: R11.2, RV1.3, U2.6 (-)
unnamed: RV2.2, RV2.3, U1.7
current_controll: D3.1 (K), R12.1, U1.1
current_reference: R9.1, R19.1, RV2.1, U1.6 (-)
voltage_controll: D2.1 (K), R13.1, U2.1
voltage_reference: P3.3, R10.2, U2.7

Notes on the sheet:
Voltage Error Amplifier
Driver
Series Pass Transistor
Current Error Amplifier
Current Ref Signal Conditioning
Voltage Ref Signal Conditioning

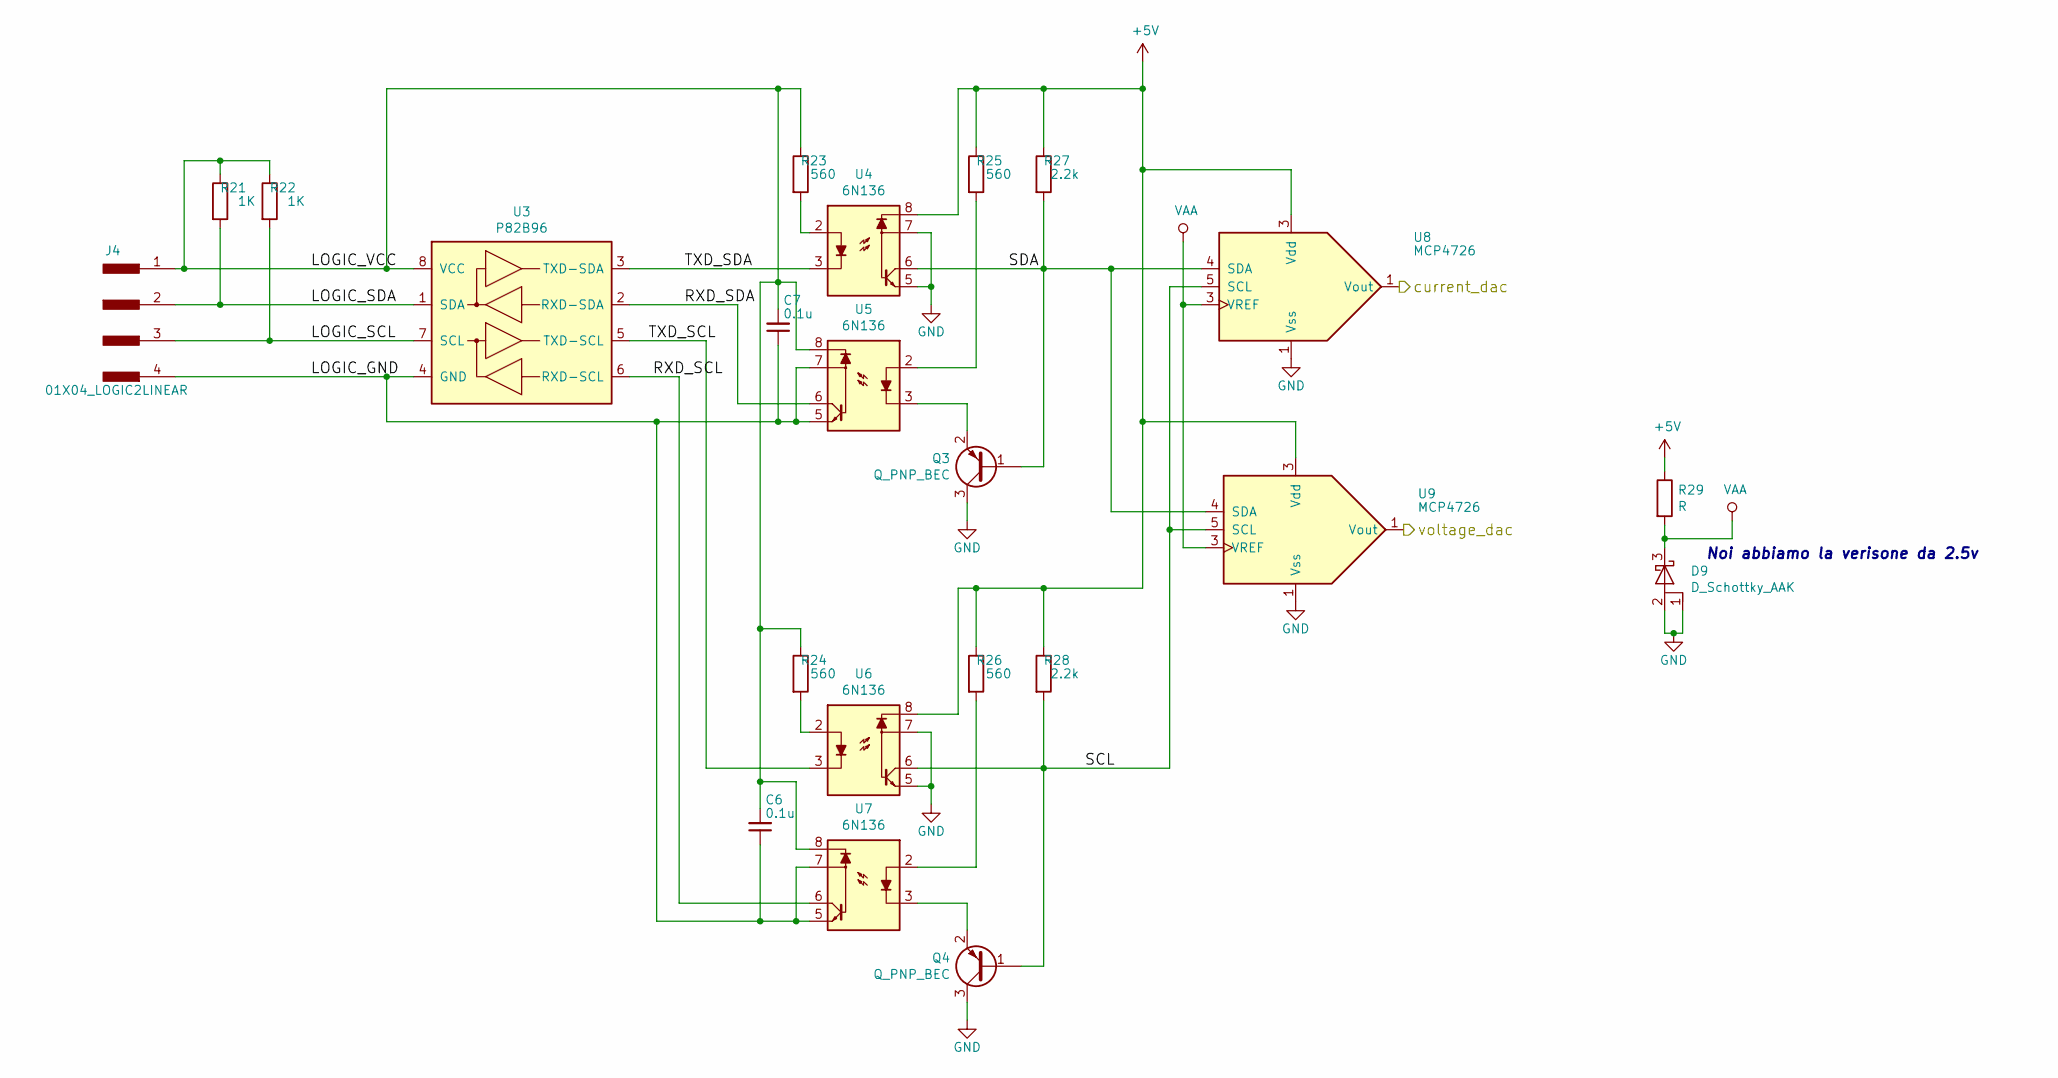
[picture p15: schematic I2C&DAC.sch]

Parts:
C6, C7: 0.1u; C_0805; Voltage 35V
D9: D_Schottky_AAK; SOT-23
J4: 01X04_LOGIC2LINEAR; Pin_Header_Straight_1x04_Pitch2.54mm
Q3, Q4: Q_PNP_BEC; SOT-23
R21, R22: 1K; R_1206_HandSoldering
R23, R24, R25, R26: 560; R_1206_HandSoldering
R27, R28: 2.2k; R_1206_HandSoldering
R29: R; R_1206_HandSoldering
U3: P82B96; SO-8
U4, U5, U6, U7: 6N136; SO-8
U8, U9: MCP4726; SOT-23-6_Handsoldering

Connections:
/I2C&DAC/LOGIC_GND: C6.1, C7.1, J4.4, U3.4 (GND), U5.5, U5.7, U7.5, U7.7
/I2C&DAC/LOGIC_SCL: J4.3, R22.2, U3.7 (SCL)
/I2C&DAC/LOGIC_SDA: J4.2, R21.2, U3.1 (SDA)
/I2C&DAC/LOGIC_VCC: C6.2, C7.2, J4.1, R21.1, R22.1, R23.1, R24.1, U3.8 (VCC), U5.8, U7.8
/I2C&DAC/RXD_SCL: U3.6 (RXD-SCL), U7.6
/I2C&DAC/RXD_SDA: U3.2 (RXD-SDA), U5.6
/I2C&DAC/SCL: Q4.1 (B), R28.2, U6.6, U8.5 (SCL), U9.5 (SCL)
/I2C&DAC/SDA: Q3.1 (B), R27.2, U4.6, U8.4 (SDA), U9.4 (SDA)
/I2C&DAC/TXD_SCL: U3.5 (TXD-SCL), U6.3
/I2C&DAC/TXD_SDA: U3.3 (TXD-SDA), U4.3
unnamed: Q3.2 (E), U5.3
unnamed: Q4.2 (E), U7.3
unnamed: R23.2, U4.2
unnamed: R24.2, U6.2
unnamed: R25.2, U5.2
unnamed: R26.2, U7.2

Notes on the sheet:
Noi abbiamo la verisone da 2.5v

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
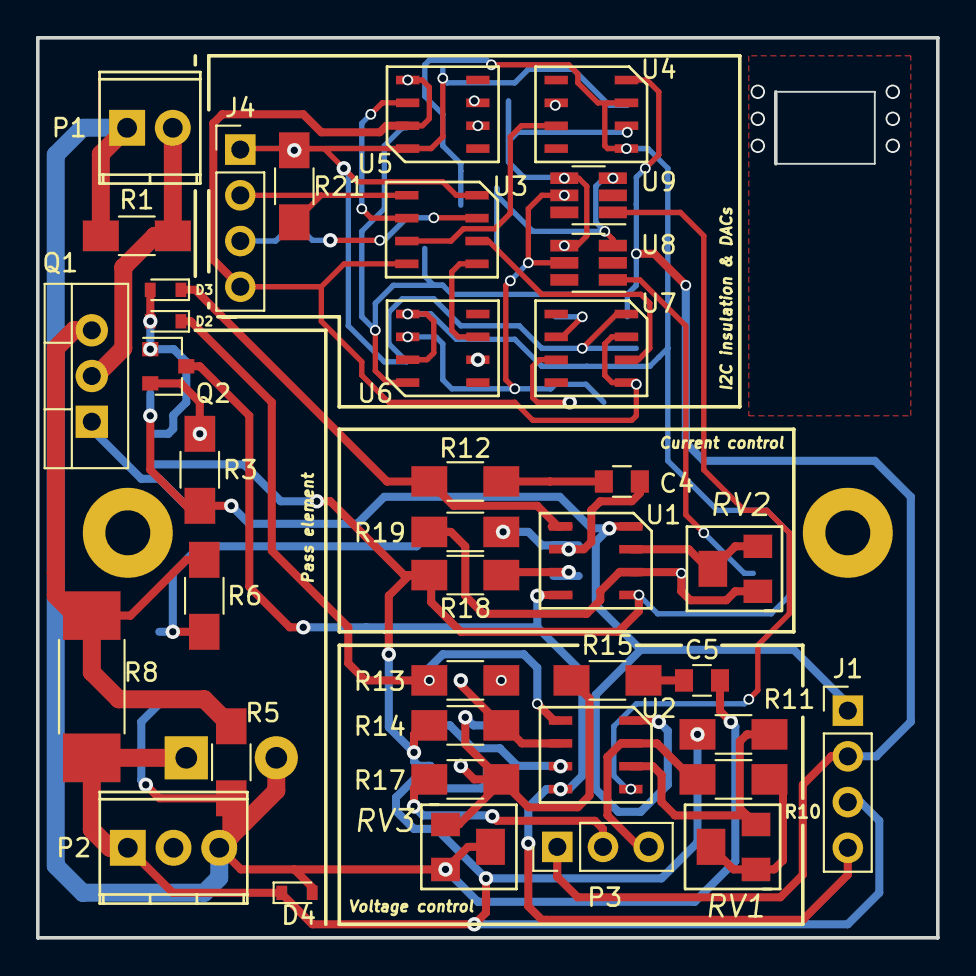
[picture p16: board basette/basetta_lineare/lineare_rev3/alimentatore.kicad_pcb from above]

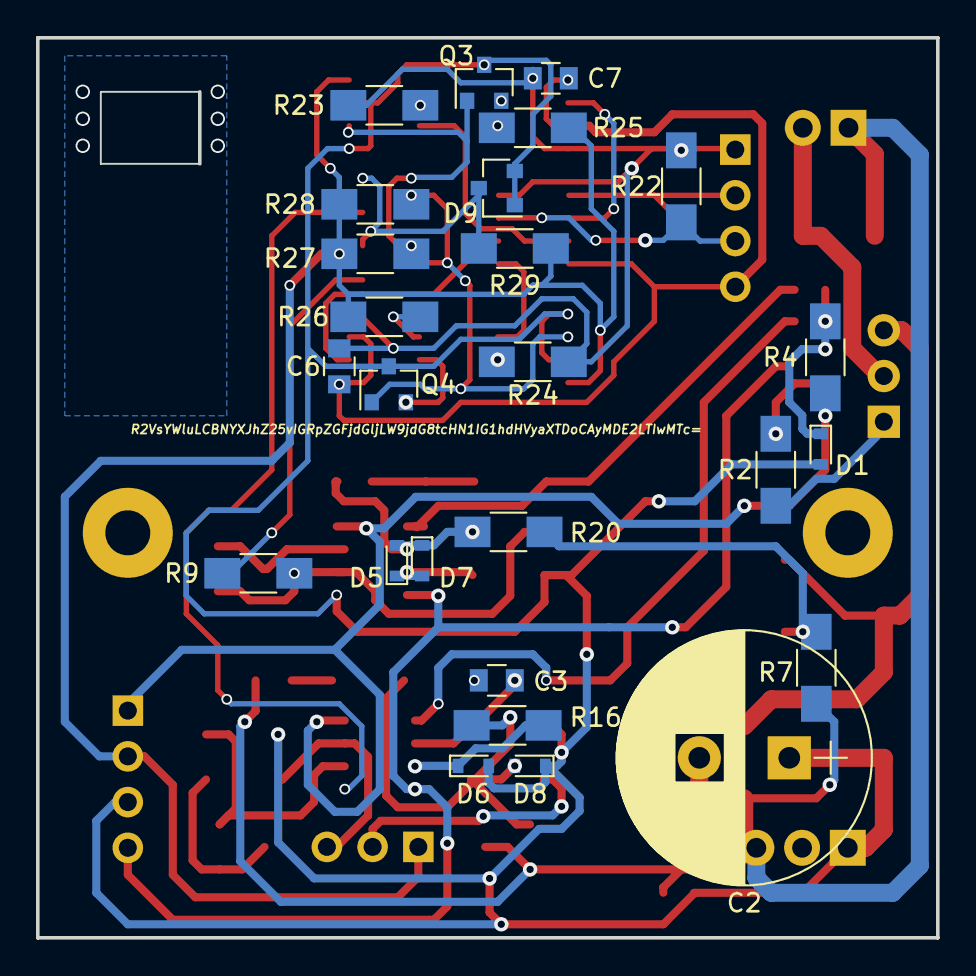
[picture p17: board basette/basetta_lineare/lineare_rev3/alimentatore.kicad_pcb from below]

Board: 2 copper layers, 50.0 x 50.0 mm, 65 parts (26 on the bottom side), 46 nets.

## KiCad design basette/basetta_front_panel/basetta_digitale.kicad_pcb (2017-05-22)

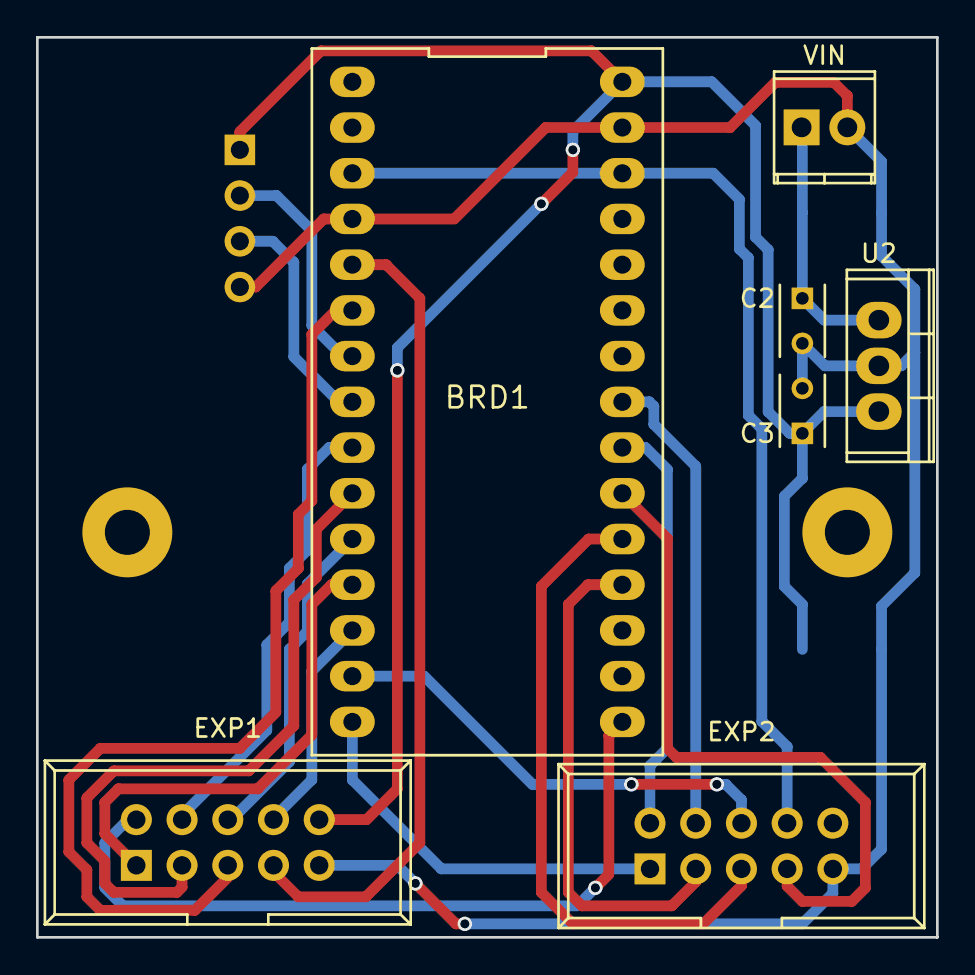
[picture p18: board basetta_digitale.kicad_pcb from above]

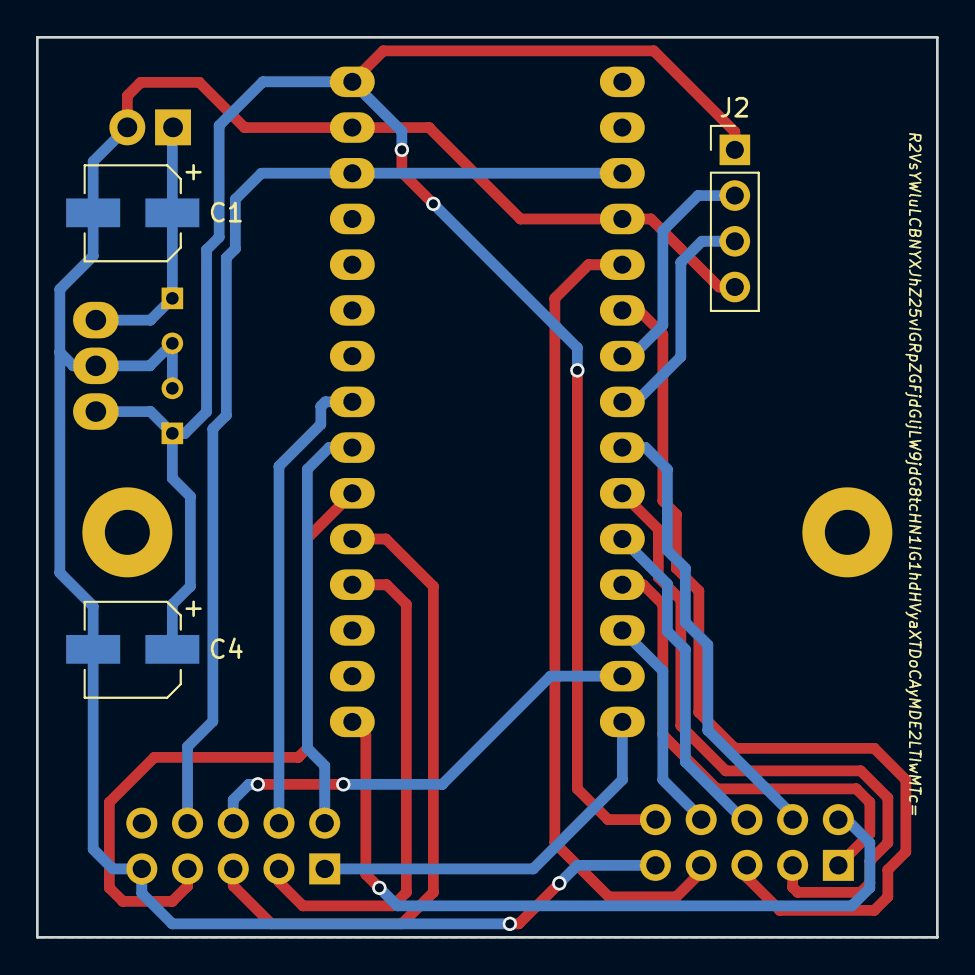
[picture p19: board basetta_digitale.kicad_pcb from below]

Board: 2 copper layers, 50.0 x 50.0 mm, 10 parts (3 on the bottom side), 21 nets.

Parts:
BRD1: NUCLEO_F3030K8; DIP-30_0_ELL
C1, C4: CP; CP_Elec_5x5.3
C2, C3: C; C_Rect_L4_W2.5_P2.5
EXP1, EXP2: CONN_02X05; IDC_Header_Straight_10pins
J2: CONN_01X04_FEMALE; Pin_Header_Straight_1x04_Pitch2.54mm
U2: LM7805CT; TO-220
VIN: LOGIC_VIN; TerminalBlock_Pheonix_MPT-2.54mm_2pol

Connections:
+5V: BRD1.30, C3.1, C4.1, EXP1.10, J2.1, U2.3
/BTN_EN1: BRD1.20, EXP2.5
/BTN_EN2: BRD1.19, EXP2.3
/BTN_ENC: BRD1.16, EXP1.2
/Beeper: BRD1.12, EXP1.1
/LCD4: BRD1.6, EXP1.5
/LCD5: BRD1.11, EXP1.6
/LCD6: BRD1.5, EXP1.7
/LCD7: BRD1.13, EXP1.8
/LCDE: BRD1.10, EXP1.3
/LCDRS: BRD1.9, EXP1.4
/MISO: BRD1.15, EXP2.1
/MOSI: BRD1.14, EXP2.6
/RESET: BRD1.3, BRD1.28, EXP2.8
/SCK: BRD1.22, EXP2.2
/SCL: BRD1.8, J2.3
/SDA: BRD1.7, J2.2
/SD_CSEL: BRD1.23, EXP2.4
/SD_DET: BRD1.21, EXP2.7
/VIN: C1.1, C2.1, U2.1, VIN.1
GND: BRD1.4, BRD1.29, C1.2, C2.2, C3.2, C4.2, EXP1.9, EXP2.9, J2.4, U2.2, VIN.2

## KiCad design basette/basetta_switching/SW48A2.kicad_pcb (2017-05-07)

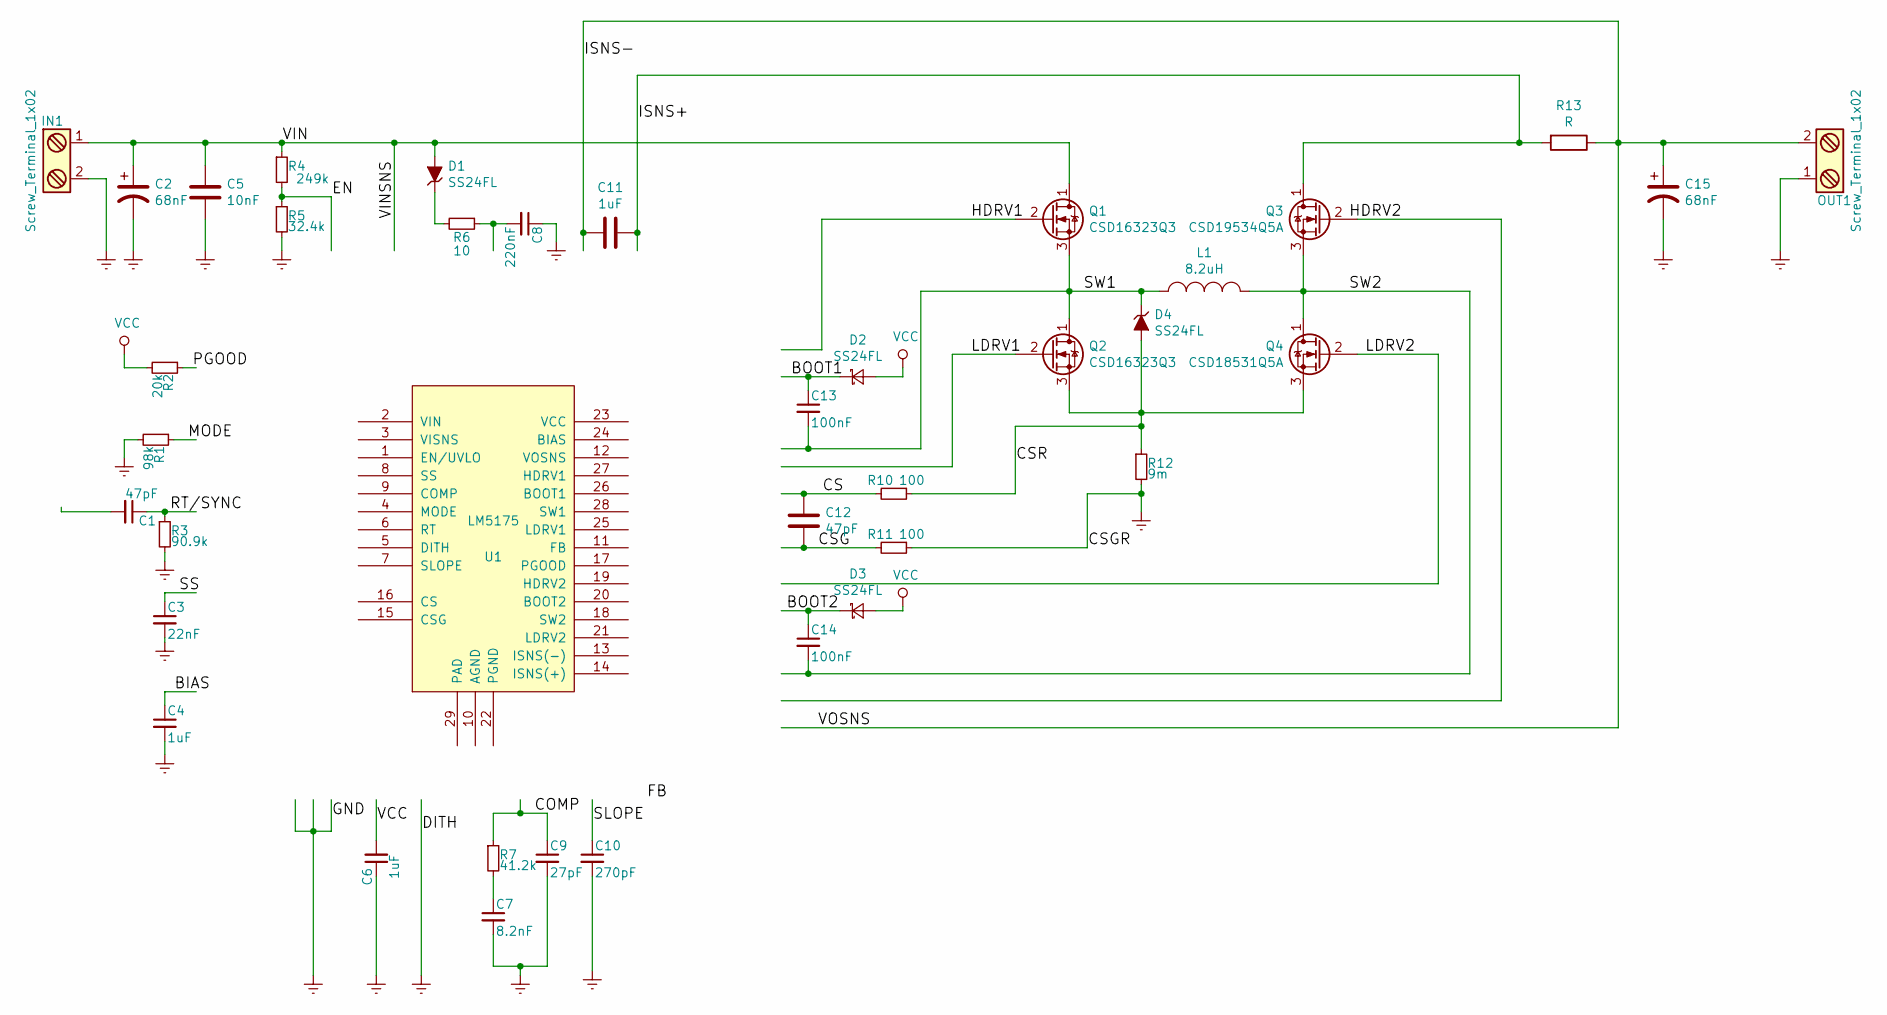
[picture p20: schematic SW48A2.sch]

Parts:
C1, C12: 47pF; C_Disc_D3.8mm_W2.6mm_P2.50mm
C2, C15: 68nF; CP_Elec_6.3x5.3
C3: 22nF; C_Disc_D3.8mm_W2.6mm_P2.50mm
C4, C6, C11: 1uF; C_Disc_D3.8mm_W2.6mm_P2.50mm
C5: 10nF; C_Disc_D3.8mm_W2.6mm_P2.50mm
C7: 8.2nF; C_Disc_D3.8mm_W2.6mm_P2.50mm
C8: 220nF; C_Disc_D3.8mm_W2.6mm_P2.50mm
C9: 27pF; C_Disc_D3.8mm_W2.6mm_P2.50mm
C10: 270pF; C_Disc_D3.8mm_W2.6mm_P2.50mm
C13, C14: 100nF; C_Disc_D3.8mm_W2.6mm_P2.50mm
D1, D2, D3, D4: SS24FL; D_SOD-123
IN1: Screw_Terminal_1x02; TerminalBlock_Pheonix_MPT-2.54mm_2pol
L1: 8.2uH; coil_craft
OUT1: Screw_Terminal_1x02; TerminalBlock_Pheonix_MPT-2.54mm_2pol
Q1, Q2: CSD16323Q3
Q3: CSD19534Q5A
Q4: CSD18531Q5A; CSD19534Q5A
R1: 98k; R_1206_HandSoldering
R2: 20k; R_1206_HandSoldering
R3: 90.9k; R_1206_HandSoldering
R4: 249k; R_1206_HandSoldering
R5: 32.4k; R_1206_HandSoldering
R6: 10; R_1206_HandSoldering
R7: 41.2k; R_1206_HandSoldering
R10, R11: 100; R_1206_HandSoldering
R12: 9m; R_1206_HandSoldering
R13: R; R_1206_HandSoldering
U1: LM5175; SOP65P640X120-28N

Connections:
/BIAS: C4.1, U1.24 (BIAS)
/BOOT1: C13.1, D2.1 (K), U1.26 (BOOT1)
/BOOT2: C14.1, D3.1 (K), U1.20 (BOOT2)
/COMP: C9.1, R7.1, U1.9 (COMP)
/CS: C12.1, R10.2, U1.16 (CS)
/CSG: C12.2, R11.2, U1.15 (CSG)
/CSR: D4.2 (A), Q2.3 (S), Q4.3 (S), R10.1, R12.1
/EN: R4.2, R5.1, U1.1 (EN/UVLO)
/FB: U1.11 (FB)
/HDRV1: Q1.2 (G), U1.27 (HDRV1)
/HDRV2: Q3.2 (G), U1.19 (HDRV2)
/ISNS+: C11.1, Q3.1 (D), R13.2, U1.14 (ISNS(+))
/ISNS-: C11.2, C15.1, OUT1.2, R13.1, U1.12 (VOSNS), U1.13 (ISNS(-))
/LDRV1: Q2.2 (G), U1.25 (LDRV1)
/LDRV2: Q4.2 (G), U1.21 (LDRV2)
/MODE: R1.1, U1.4 (MODE)
/PGOOD: R2.1, U1.17 (PGOOD)
/RT/SYNC: C1.1, R3.1, U1.6 (RT)
/SLOPE: C10.1, U1.7 (SLOPE)
/SS: C3.1, U1.8 (SS)
/SW1: C13.2, D4.1 (K), L1.1, Q1.3 (S), Q2.1 (D), U1.28 (SW1)
/SW2: C14.2, L1.2, Q3.3 (S), Q4.1 (D), U1.18 (SW2)
/VIN: C2.1, C5.1, D1.2 (A), IN1.1, Q1.1 (D), R4.1, U1.3 (VISNS)
Earth: C2.2, C3.2, C4.2, C5.2, C6.1, C7.2, C8.1, C9.2, C10.2, C15.2, IN1.2, OUT1.1, R1.2, R3.2, R5.2, R11.1, R12.2, U1.5 (DITH), U1.10 (AGND), U1.22 (PGND), U1.29 (PAD)
unnamed: C7.1, R7.2
unnamed: D1.1 (K), R6.2
VCC: C6.2, D2.2 (A), D3.2 (A), R2.2, U1.23 (VCC)

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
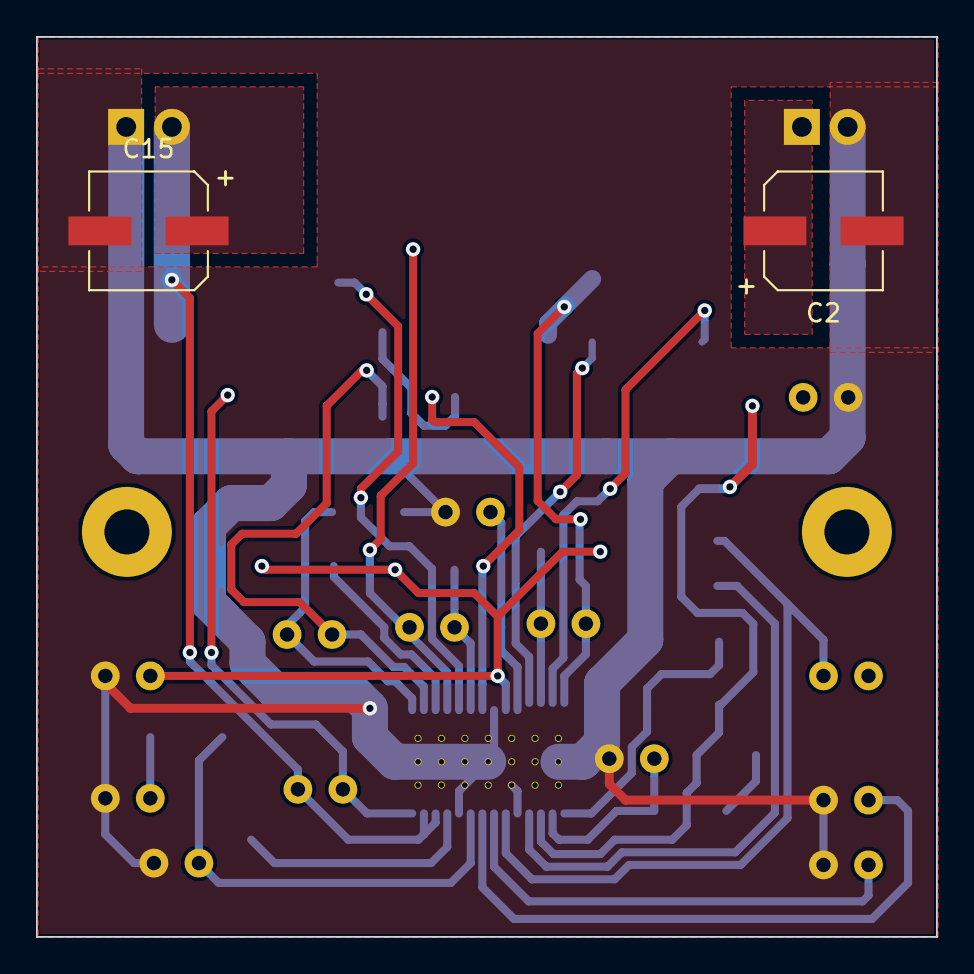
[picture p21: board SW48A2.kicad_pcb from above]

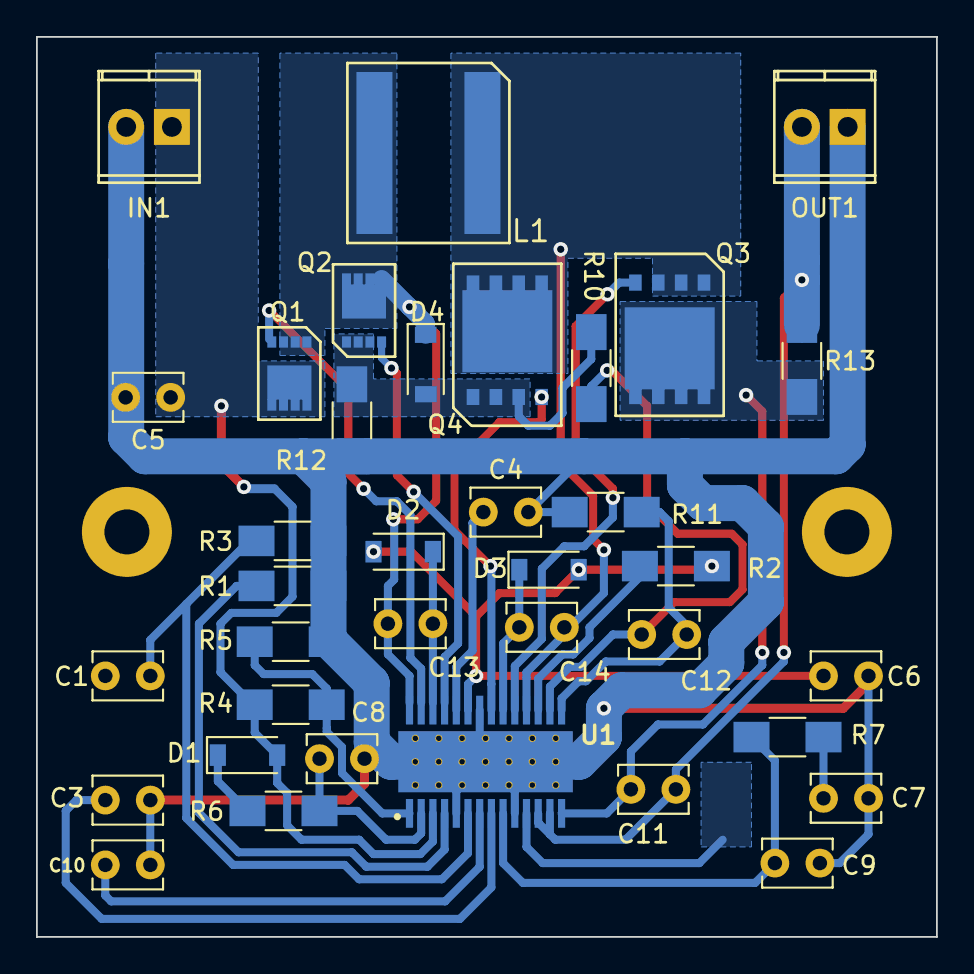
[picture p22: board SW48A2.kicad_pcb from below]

Board: 2 copper layers, 50.0 x 50.0 mm, 38 parts (36 on the bottom side), 27 nets.

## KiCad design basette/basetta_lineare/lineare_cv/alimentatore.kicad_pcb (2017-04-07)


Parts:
C1: 1000u; CP_Radial_D14.0mm_P5.00mm; Voltage 50V
C4: 2200p; C_Disc_D3.0mm_W2.0mm_P2.50mm; Voltage 50V
C5: 6.8u; C_Disc_D3.0mm_W2.0mm_P2.50mm; Voltage 35V
C6: 470u; CP_Radial_D14.0mm_P5.00mm; Voltage 50V
C7, C8: NP; CP_Radial_D7.5mm_P2.50mm
D1, D3, D6, D8: 1N4148; D_DO-41_SOD81_P2.54mm_Vertical_AnodeUp
D7: D_Small; D_DO-41_SOD81_P2.54mm_Vertical_AnodeUp
J1: TP6; Measurement_Point_Round-SMD-Pad_Small
J2: TP5; Measurement_Point_Round-SMD-Pad_Small
P1, P6: LOAD_POWER_01X02; TerminalBlock_Pheonix_PT-3.5mm_2pol
P2, P3: CONN_01X03; TerminalBlock_Pheonix_PT-3.5mm_3pol
P4: CONN_01X03; Pin_Header_Straight_1x03_Pitch2.54mm
P5: LOAD_POWER_01X02; Pin_Header_Straight_1x02_Pitch2.54mm
Q1: Q_NMOS_GDS; TO-220_Vertical
Q2: Q_PNP_EBC; TO-92_Rugged
R2: 2K; R_1210_HandSoldering
R3: 50; R_1210_HandSoldering
R4: 1K2; R_1210_HandSoldering
R5: 5K; R_1210_HandSoldering
R6: 1M5; R_1210_HandSoldering
R9, R13: 1K; R_1210_HandSoldering
R12: 21,5; R_1210_HandSoldering
R14: R; R_1210_HandSoldering
R16: 390; R_1210_HandSoldering
R19: 0,1; R_1210_HandSoldering
RV3: 50K; Potentiometer_Trimmer_Bourns_3299W
U2: LM741; DIP-8_W7.62mm_LongPads

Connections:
+5V: P4.1, P6.2
+12VA: P3.1, R4.1, R5.2, U2.7 (V+)
-12VA: P3.3, Q2.3 (C), U2.4 (V-)
/-OUTPUT: C1.2, C5.1, C6.2, C8.1, D8.2 (A), P1.1, P2.3, R2.2, R16.1, RV3.2, RV3.3
/GATE: J1.1, Q1.1 (G), R3.2
/GATE_CONTROLL: Q2.1 (E), R3.1, R4.2
/SOURCE: Q1.3 (S), R16.2, R19.1
/VIN: C1.1, P1.2, Q1.2 (D), R2.1
/VOLTAGE_LIMIT: P4.3, P5.1
Earth: C7.1, C8.2, P2.2
GND: C6.1, C7.2, D1.2 (A), D6.2 (A), D7.1 (K), D8.1 (K), P2.1, P3.2, P5.2, P6.1, R9.2, R19.2
unnamed: C4.1, R9.1, U2.2 (-)
unnamed: C4.2, R6.2
unnamed: C5.2, R12.1
unnamed: D1.1 (K), D3.2 (A), J2.1, Q2.2 (B), R5.1
unnamed: D3.1 (K), R6.1, U2.6
unnamed: D6.1 (K), R13.1, U2.3 (+)
unnamed: D7.2 (A), R12.2, R13.2, R14.2, RV3.1
unnamed: P4.2, R14.1

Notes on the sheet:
Voltage Error Amplifier
Driver
Series Pass Transistor

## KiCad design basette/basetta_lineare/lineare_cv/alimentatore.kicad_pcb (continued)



Board: 2 copper layers, 78.8 x 70.0 mm, 34 parts (8 on the bottom side), 19 nets.

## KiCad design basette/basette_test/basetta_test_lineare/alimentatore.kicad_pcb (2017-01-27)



Board: 2 copper layers, 117.6 x 97.8 mm, 83 parts (2 on the bottom side), 40 nets.

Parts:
C1, C6: CP1_Small; C_Radial_D14_L31.5_P5
C2, C3, C4, C5, C18: C_Small; C_Disc_D3_P2.5
C7, C8: C_Small; C_Radial_D7.5_L11.2_P2.5
C9, C10, C11, C15, C16, C17: 470u; C_Radial_D8_L21_P3.8
C12, C13, C14: .33u; C_Disc_D3_P2.5
D1, D2, D3, D4, D5, D6, D7, D8: D_Small; Diode_DO-41_SOD81_Vertical_AnodeUp
J1: TP6; Pin_Header_Straight_1x01
J2: TP5; Pin_Header_Straight_1x01
J3: TP7; Pin_Header_Straight_1x01
J10: TP1; Pin_Header_Straight_1x01
J11: TP2; Pin_Header_Straight_1x01
J12: TP3; Pin_Header_Straight_1x01
L1: L_Small; Resistor_Horizontal_RM7mm
P1: LOAD_POWER_01X02; mors_2p
P2: CONN_01X03; mors_3p
P3: CONN_01X04; Pin_Header_Straight_1x04
P4, P7: CONN_01X03; Pin_Header_Straight_1x03
P5: CONN_01X02; Pin_Header_Straight_1x02
P6: LOGIC_POWER_01X03; mors_3p
P8, P9: CONN_01X01; Pin_Header_Straight_1x01
Q1: Q_NMOS_GDS; TO-220_Neutral123_Vertical_LargePads
Q2: Q_PNP_EBC; TO-92_Rugged
R1, R2, R3, R4, R5, R6, R7, R8, R9, R10, R11, R12, R13, R14, R15, R16, R17, R18, R19, R20, R21, R22, R23, R24, R25, R26, R27: R; Resistor_Horizontal_RM10mm
R28, R29: R_Small; R_1210_HandSoldering
RV1, RV2, RV3: POT; Potentiometer_Trimmer-Piher-PT15-h5_vertical
U1, U2, U4: LM741; DIP-8_W7.62mm_LongPads
U3: LM393; DIP-8_W7.62mm_LongPads
U7: LM7805CT; TO-220
U8: LM7812CT; TO-220
U9: LM7912CT; TO-220

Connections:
+5V: C15.1, J10.1, P3.2, P4.1, R28.2, R29.2, RV1.3, U7.3
+12VA: C9.1, C13.2, C16.1, J11.1, R4.1, R5.2, R23.2, U1.7, U2.7, U3.8, U4.7, U7.1, U8.3
-12VA: C17.2, J12.1, Q2.3, U1.4, U2.4, U3.4, U4.4, U9.3
/-OUTPUT: C1.2, C5.1, C6.2, C8.1, D8.2, P1.2, P2.3, R1.2, R16.1, R18.1, R27.2, RV3.2, RV3.3
/AN_CREF: P7.3, RV2.2, RV2.3, U4.6
/CC_INDICATOR: P3.3, R28.1, U3.1
/CC_SENSE: C3.1, D2.1, R20.1, U1.6
/CURRENT_LIMIT: P7.1, P8.1
/CURREN_MES: P5.2, R21.1, R25.1
/CV_INDICATOR: P3.4, R29.1, U3.7
/CV_SENSE: D3.1, R6.1, R22.1, U2.6
/VOLTAGE_LIMIT: P4.3, P9.1
/VOLTAGE_MES: P5.1, R26.2, R27.1
Earth: C7.1, C8.2, P2.2
GND: C6.1, C7.2, C9.2, C10.2, C11.1, C12.1, C13.1, C14.1, C15.2, C16.2, C17.1, C18.2, D1.2, D6.2, D7.1, D8.1, P2.1, P3.1, P6.2, R9.2, R10.1, R19.2, R24.1, R25.2, R26.1, U4.3, U7.2, U8.2, U9.1
unnamed: C1.1, P1.1, Q1.2, R1.1
unnamed: C2.1, R2.1, R3.1
unnamed: C2.2, L1.1, R2.2, R4.2
unnamed: C3.2, D4.1, D5.2, R8.2, R11.1, U1.2
unnamed: C4.1, R9.1, U2.2
unnamed: C4.2, R6.2
unnamed: C5.2, R12.1
unnamed: C10.1, C14.2, P6.3, U8.1
unnamed: C11.2, C12.2, P6.1, U9.2
unnamed: C18.1, R15.1, RV2.1, U4.2
unnamed: D1.1, D2.2, D3.2, J2.1, Q2.2, R5.1
unnamed: D4.2, D5.1, R10.2, U1.3
unnamed: D6.1, R13.1, U2.3
unnamed: D7.2, R12.2, R13.2, R14.2, RV3.1
unnamed: J1.1, Q1.1, R3.2
unnamed: J3.1, R8.1, R17.1, R18.2
unnamed: L1.2, Q2.1
unnamed: P4.2, R14.1
unnamed: P7.2, R11.2
unnamed: Q1.3, R7.2
unnamed: R15.2, RV1.1, RV1.2
unnamed: R7.1, R16.2, R17.2, R19.1, R21.2
unnamed: R20.2, U3.3
unnamed: R22.2, U3.6
unnamed: R23.1, R24.2, U3.2, U3.5

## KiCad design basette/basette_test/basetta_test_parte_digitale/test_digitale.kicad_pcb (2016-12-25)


Board: 2 copper layers, 40.6 x 52.1 mm, 12 parts (0 on the bottom side), 16 nets.

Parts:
D13, D14: Led_Small; SMB_Handsoldering
P1: CONN_01X03; Pin_Header_Straight_1x03
P3: UART_01X03; Pin_Header_Straight_1x03
P4: ICSP_01X06; Pin_Header_Straight_1x06
R1, R2: R; Resistor_Horizontal_RM10mm
R30, R31: 390; Resistor_SMD+THTuniversal_0805to2512_HandSoldering
U4: PIC16F18323; DIP-14_W7.62mm_LongPads
U5, U6: MCP4726; SOT-23-6_Handsoldering

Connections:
+5V: P4.2, R1.1, R2.1, U4.1, U5.3, U6.3
/ICSPCLK: P4.5, U4.12
/ICSPDAT: P4.4, U4.13
/RX: P3.3, U4.2
/SCL: R2.2, U4.10, U5.5, U6.5
/SDA: R1.2, U4.9, U5.4, U6.4
/STATUS_LED_1: R31.2, U4.5
/STATUS_LED_2: R30.2, U4.11
/TX: P3.2, U4.3
/dac_1_out: P1.1, U5.1
/dac_2_out: P1.2, U6.1
/~MCLR: P4.1, U4.4
GND: D13.1, D14.1, P1.3, P3.1, P4.3, U4.14, U5.2, U6.2
unnamed: D13.2, R30.1
unnamed: D14.2, R31.1
VAA: U5.6, U6.6

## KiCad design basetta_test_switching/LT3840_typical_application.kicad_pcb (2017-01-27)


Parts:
C1: 2200pF; C_Rect_L13_W4_P10
C2, C4: 1uF; C_Rect_L18_W6_H12_P15
C3: 4.7uF; C_Rect_L7_W3.5_P5
Cin1, Cin2: 68uF; C_Radial_D10_L13_P5
Cout2: 270uF; C_Radial_D13_L21_P5
D1: 1N4448; Diode_DO-35_SOD27_Horizontal_RM10
J1, J3: Screw_Terminal_1x02; mors_2p
J2: Screw_Terminal_1x01; mors_2p
L1: 5.6uH; Inductor_Vishay_IHSM-5832
L2: 33uH; Inductor_Taiyo-Yuden_NR-40xx_HandSoldering
M1, M2: Q_NMOS_GDS; TO-247_Vertical_Neutral123_largePads
R1: 49.9k; Resistor_Horizontal_RM7mm
R2: 20k; Resistor_Horizontal_RM7mm
R3: 100k; Resistor_Horizontal_RM7mm
R4: 301k; Resistor_Horizontal_RM7mm
Rsense1: 5m; R_2816_HandSoldering
U1: LT3840; TSSOP-28_4.4x9.7mm_Pitch0.65mm

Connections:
/AUXBST: C2.2, U1.28 (AUXBST)
/AUXSW: C2.1, L2.1, U1.1 (AUXSW)
/AUXSW2: L2.2, U1.27 (AUXSW2)
/BG: M2.1 (G), U1.25 (BG)
/BGRTN: C3.2, U1.24 (BGRTN)
/BOOST: C4.1, D1.1 (K), U1.23 (BOOST)
/FB: R3.1, R4.2, U1.7 (FB)
/INTVCC: C3.1, D1.2 (A), U1.26 (INTVCC)
/RT: R1.1, U1.5 (RT)
/SENSE+: L1.2, Rsense1.2, U1.19 (SENSE+)
/SENSE-: Cout2.1, J3.2, R4.1, Rsense1.1, U1.20 (SENSE-)
/SW: C4.2, L1.1, M1.3 (S), M2.2 (D), U1.21 (SW)
/TG: M1.1 (G), U1.22 (TG)
/VC: R2.1, U1.8 (VC)
/VIN: Cin1.1, Cin2.1, J1.1, M1.2 (D), U1.3 (AUXVIN), U1.12 (UVLO), U1.13 (EN), U1.14 (VIN)
GND: C1.2, Cin1.2, Cin2.2, Cout2.2, J1.2, J3.1, M2.3 (S), R1.2, R3.2, U1.2 (PGND), U1.4 (SYNC), U1.10 (MODE), U1.11 (OVLO), U1.15 (GND), U1.18 (ICOMP), U1.29 (GND)
unnamed: C1.1, R2.2
unnamed: J2.1, U1.9 (PG)

Board: 2 copper layers, 21 parts (0 on the bottom side), 18 nets, no tracks yet.

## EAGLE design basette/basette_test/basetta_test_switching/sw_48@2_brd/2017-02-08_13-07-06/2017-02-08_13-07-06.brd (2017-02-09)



Board: 4 copper layers, 66 parts (2 on the bottom side), 27 nets.

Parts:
Cbias: 1206
Cboot1, Cboot2: 0603
Cbulk: SM_RADIAL_6.3AMM
Ccomp: 0201
Ccomp2: 0805
Ccs: 0603
Cdith: 0805
Cf: 0603
Cin: 1206_190
Cisns: 0805
Cout_1, Cout_2: 2220_280
Coutx2_1, Coutx2_2, Coutx2_3, Coutx2_4, Coutx2_5, Coutx3_1, Coutx3_2, Coutx3_3, Coutx3_4, Coutx3_5: 2220
Coutx_1, Coutx_2, Coutx_3, Coutx_4, Coutx_5: 2220
Cslope: 0603
Css: 0603
Csync: 0805
Cvcc: 0603
D2: SOD-123F
D3: SMB
Dboot1, Dboot2: SOD-123F
Df: SOD-123F
GND, GND1: TP-1502
INSNS+: TP-1502
INSNS-: TP-1502
L1: XAL1010
M1, M2: DQG0008A
M3, M4: TRANS_NexFET_Q5A
Rcomp: 0402
Rcsg: 0603
Rcsp: 0603
Rf: 0603
Rfbb: 0603
Rfbt: 0603
Risns: 2512
Risnsn: 0805
Risnsp: 0805
Rmode: 0603
Rpg: 0603
Rsense: 4527
Rt: 0402
Ruvb: 0402
Ruvt: 0402
U1: PWP0028F_N
V1: TP-1502
VIN: TP-1502
VOUT: TP-1502
Vsync: TP-1502

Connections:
0: Cbias.2, Cbulk.2, Ccomp.2, Ccomp2.2, Cdith.1, Cdith.2, Cf.2, Cin.2, Cisns.1, Cisns.2, Cout_1.2, Cout_2.2, Coutx2_1.2, Coutx2_2.2, Coutx2_3.2, Coutx2_4.2, Coutx2_5.2, Coutx3_1.2, Coutx3_2.2, Coutx3_3.2, Coutx3_4.2, Coutx3_5.2, Coutx_1.2, Coutx_2.2, Coutx_3.2, Coutx_4.2, Coutx_5.2, Cslope.2, Css.2, Cvcc.2, GND.1, GND1.1, INSNS+.1, INSNS-.1, Rcsg.2, Rfbb.2, Risnsn.1, Risnsp.1, Rmode.2, Rsense.2, Rt.2, Ruvb.2, U1.5, U1.10, U1.13, U1.14, U1.22, U1.29
1: Css.1, U1.8
2: Rmode.1, U1.4
3: Cbulk.1, Cin.1, Df.2, M1.5, M1.6, M1.7, M1.8, M1.9, Ruvt.1, U1.3, VIN.1
4: Ccomp2.1, Rcomp.1, U1.9
5: Ruvb.1, Ruvt.2, U1.1
6: Csync.1, Rt.1, U1.6
7: D2.2, M2.1, M2.2, M2.3, M4.1, M4.2, M4.3, Rcsp.2, Rsense.1
8: Cslope.1, U1.7
9: Cf.1, Rf.2, U1.2
10: Ccs.1, Rcsp.1, U1.16
11: Ccs.2, Rcsg.1, U1.15
15: Rpg.2, U1.17
16: Rfbb.1, Rfbt.2, U1.11
18: Cboot1.1, Dboot1.1, U1.26
19: Cbias.1, Cout_1.1, Cout_2.1, Coutx2_1.1, Coutx2_2.1, Coutx2_3.1, Coutx2_4.1, Coutx2_5.1, Coutx3_1.1, Coutx3_2.1, Coutx3_3.1, Coutx3_4.1, Coutx3_5.1, Coutx_1.1, Coutx_2.1, Coutx_3.1, Coutx_4.1, Coutx_5.1, D3.1, M3.5, M3.6, M3.7, M3.8, M3.9, Rfbt.1, Risns.1, Risns.2, Risnsn.2, Risnsp.2, U1.12, U1.24, V1.1, VOUT.1
20: Cboot2.2, D3.2, L1.2, M3.1, M3.2, M3.3, M4.5, M4.6, M4.7, M4.8, M4.9, U1.18
21: Cvcc.1, Dboot1.2, Dboot2.2, Rpg.1, U1.23
22: Cboot1.2, D2.1, L1.1, M1.1, M1.2, M1.3, M2.5, M2.6, M2.7, M2.8, M2.9, U1.28
23: Cboot2.1, Dboot2.1, U1.20
24: Ccomp.1, Rcomp.2
25: Df.1, Rf.1
30: M2.4, U1.25
31: M1.4, U1.27
32: M3.4, U1.19
33: M4.4, U1.21
67: Csync.2, Vsync.1

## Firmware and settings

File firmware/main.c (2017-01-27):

/**
  Generated Main Source File

  Company:
    Microchip Technology Inc.

  File Name:
    main.c

  Summary:
    This is the main file generated using MPLAB(c) Code Configurator

  Description:
    This header file provides implementations for driver APIs for all modules selected in the GUI.
    Generation Information :
        Product Revision  :  MPLAB(c) Code Configurator - 4.15
        Device            :  PIC16F18323
        Driver Version    :  2.00
    The generated drivers are tested against the following:
        Compiler          :  XC8 1.35
        MPLAB             :  MPLAB X 3.40
*/

/*
    (c) 2016 Microchip Technology Inc. and its subsidiaries. You may use this
    software and any derivatives exclusively with Microchip products.

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
    IN NO EVENT WILL MICROCHIP BE LIABLE FOR ANY INDIRECT, SPECIAL, PUNITIVE,
    INCIDENTAL OR CONSEQUENTIAL LOSS, DAMAGE, COST OR EXPENSE OF ANY KIND
    WHATSOEVER RELATED TO THE SOFTWARE, HOWEVER CAUSED, EVEN IF MICROCHIP HAS
    BEEN ADVISED OF THE POSSIBILITY OR THE DAMAGES ARE FORESEEABLE. TO THE
    FULLEST EXTENT ALLOWED BY LAW, MICROCHIP'S TOTAL LIABILITY ON ALL CLAIMS IN
    ANY WAY RELATED TO THIS SOFTWARE WILL NOT EXCEED THE AMOUNT OF FEES, IF ANY,
    THAT YOU HAVE PAID DIRECTLY TO MICROCHIP FOR THIS SOFTWARE.

    MICROCHIP PROVIDES THIS SOFTWARE CONDITIONALLY UPON YOUR ACCEPTANCE OF THESE
    TERMS.
*/

#include "mcc_generated_files/mcc.h"

/*
                         Main application
 *uint16_t tick_count = 0;
uint8_t serial_write_buffer[5];
uint8_t serial_read_buffer[5]; non serve un buffer di lettura, credo....
uint8_t serial_read_index = 0;
bool got_command = 0;
 */


/*
void Update_Mesuraments(){
    uint16_t convertedValue;
    
    serial_write_buffer[0]='H';
            
    ADC_StartConversion(channel_ANC2);
    while(!ADC_IsConversionDone());
    convertedValue = ADC_GetConversionResult();
    
    serial_write_buffer[1] = convertedValue >>8;
    serial_write_buffer[2] = convertedValue;
    
    ADC_StartConversion(channel_ANC3);
    while(!ADC_IsConversionDone());
    convertedValue = ADC_GetConversionResult();
    
    serial_write_buffer[3] = convertedValue >>8;
    serial_write_buffer[4] = convertedValue;
    
    for(int index = 0; index<5; index++){
        EUSART_Write(serial_write_buffer[index]);
    }
    TMR0_StartTimer();
}
*/
/*
void TMR0_CUSTOM_ISR(){
    TMR0_StopTimer();
    
    tick_count++;
    
    if(tick_count % 5 == 0 && !got_command){
        
        uint8_t serial_read = EUSART_Read();
        
        switch (serial_read){
            case 'K':
                got_command = 1;
                Update_Mesuraments();
                break;  
            case 'L':
                got_command = 1;
                //Get_New_Values();
        }
    }
    
    if (tick_count == 255){
        tick_count = 0;
    }
 */       
    
    

void main(void)
{
    // initialize the device
    SYSTEM_Initialize();

    // When using interrupts, you need to set the Global and Peripheral Interrupt Enable bits
    // Use the following macros to:

    // Enable the Global Interrupts
    INTERRUPT_GlobalInterruptEnable();

    // Enable the Peripheral Interrupts
    INTERRUPT_PeripheralInterruptEnable();

    // Disable the Global Interrupts
    //INTERRUPT_GlobalInterruptDisable();

    // Disable the Peripheral Interrupts
    //INTERRUPT_PeripheralInterruptDisable();
    
    /*
    void *functionPtr = &TMR0_CUSTOM_ISR;
    
    TMR0_SetInterruptHandler(functionPtr);
    */
    
    while (1)
    {
        printf(scanf());
    }
}

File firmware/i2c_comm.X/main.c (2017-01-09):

#include "mcc_generated_files/mcc.h"

void main(void) {

    uint8_t writeBuffer[10]; // Data to write to slave
    I2C1_MESSAGE_STATUS status; // I2C status


    SYSTEM_Initialize(); // Initialize the device
    // Inside: I2C1_Initialize() - Initializes the MSSP
    //         Manually set RB0 and RB1 as digital input

    INTERRUPT_GlobalInterruptEnable();

    // Enable the Peripheral Interrupts
    INTERRUPT_PeripheralInterruptEnable();
    
    static uint16_t address = (0xC0 / 2);	
    static uint8_t length = 1;
    static uint8_t command[3] = {0b01110000,0b11001100,0b11000000};
    
    static I2C1_MESSAGE_STATUS I2C_Wflag, I2C_Rflag;

    //[0b11000000,0b01110000,0b11001100,0b11000000]
    //[0b11000000,0b01110000,0b01100110,0b01100000]
    //[0b11000000,0b01110000,0b00110011,0b00110000]
    //[0b11000000,0b01110000,0b01110000,0b00000000]
    //[0b11000000,0b01110000,0b01001100,0b11000000]



    
    length = 3;
    address = 0b1100000; 
	
    while (1) {

        /* Start a I2C Write */
        I2C1_MasterWrite(&command, length, address, &I2C_Wflag);
        
        if (I2C_Wflag == I2C1_MESSAGE_FAIL){
              
            
        } 
        
        while (I2C_Wflag != I2C1_MESSAGE_COMPLETE);
        __delay_ms(500);
    }
}

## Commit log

2016-12-24 First Commit, first version of linear stage
    [alimentatore.csv, alimentatore.kicad_pcb, alimentatore.sch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]
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2016-12-26 Updating schematics to reflect the dautherboard desing approch. The uC + DAC schematics has been removed. The dac reference has also been removed. in ordert to switch between pic or manual mode two j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
    [alimentatore.kicad_pcb, alimentatore.sch, pic_dac.sch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]
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2017-01-02 renamed lineare folder to reflect it's content
    [alimentatore.csv, alimentatore.kicad_pcb, alimentatore.sch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]
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2017-01-04 Created spreadsheet to understand in detail the DAC register
    [Data_Decoding_Helper.ods]
2017-01-06 Updating PCB routing and adding PCB edge
    [alimentatore.kicad_pcb]
2017-01-06 Added a spreadsheet to explaint the varius DAC commands. The spreadsheet can also craft the command in the format used by the bus pirate. Created a project to test the MCC generated libraries. So far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
    [Data_Decoding_Helper.ods, _saved_alimentatore.sch, alimentatore.kicad_pcb]
2017-01-06 Proceding with upgrading @Gela routing
    [alimentatore.kicad_pcb]
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2017-01-06 Splitted one of the daughterboard connector to allow a better routing
    [Data_Decoding_Helper.ods, _saved_alimentatore.sch, alimentatore.kicad_pcb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]
2017-01-07 Created the reference of the i2c implementation on mplab. This project it's now fully working, just swap the walues in the array.
    [alimentatore.kicad_pcb]
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2017-01-09 Finished PCB "Parte lineare" routing
    [alimentatore.kicad_pcb]
2017-01-09 added a firmware project for all of the functions modified pcb in order to make it with the matireals avaible
    [Data_Decoding_Helper.ods]
2017-01-12 Updated BOM list and components value
    [alimentatore.sch, reference_supply.sch]
2017-01-27 changed some of the boarda. Added the file of the stm32 nucleo board.
    [Data_Decoding_Helper.ods, LT3840_typical_application.kicad_pcb, LT3840_typical_application.sch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]
2017-01-30 reorganized the simulation folder, added the switching tracking simulation
    [_saved_test_lineare_switching.sch, test_lineare_switching.sch]
2017-02-01 Addin DC/DC boost-buck eeschema
    [Buck-Boost-DCDC.kicad_pcb, Buck-Boost-DCDC.sch]
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2017-02-09 Added switching controller bom
    [sw48@2_BOM.xls]
2017-02-13 Adding schematic of boost/buck switching stage
    [SW48A2.kicad_pcb, SW48A2.sch]
2017-02-16 Finished footprints association -> ready for PCB routing!
    [SW48A2.kicad_pcb, SW48A2.sch]
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2017-02-23 Updated EESCHEMA , full footprin association and started PCB
    [SW48A2.kicad_pcb, SW48A2.sch]
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2017-03-05 Progress on the routng of the H-Bridge
    [BOM_4712046_30.xls, SW48A2.kicad_pcb, SW48A2.sch]
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2017-03-06 PCB of SW48A2
    Need more footprint for wire pad for single layer routing... need revision
    [SW48A2.kicad_pcb, SW48A2.sch]
2017-03-07 Updating PCB routing of sw48
    [SW48A2.kicad_pcb]
2017-03-07 Finished PCB routing of SW48A2->ready for revision and prototyping
    [SW48A2.kicad_pcb]
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2017-03-13 Revised the linear part to adapt to the results of preliminary tests
    [alimentatore.csv, alimentatore.kicad_pcb, alimentatore.ods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]
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2017-04-06 New board that include NUCLEO F303K8
    [basetta_digitale.kicad_pcb, basetta_digitale.sch]
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2017-04-11 New pcb about NUCLEO(ARM) and DAC for linear PSU regulation
    [basetta_digitale.sch]
2017-04-12 reviewed the schematics made by gela
    1-sistemare il bus
    2-finire la resistenza di biasing del reference
    3-mettere degli amplificatori per disaccopiare i dac
    4-predisporre per gli ingressi degli adc
    5-capire come gesire le alimentazioni ci penso io
    [basetta_digitale.sch]
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2017-04-18 drawn a better schematic
    This new schemati reflects better the function of eatch passives and also uses less labes
    [SW48A2.sch]
2017-04-19 Labels on schematics, annotation and component assocation
    done
    [SW48A2.kicad_pcb, SW48A2.sch]
2017-04-19 Started Routing
    Changed pad assocation on the lm5175 footprint. Layed out the power components, in an efficient layout for shilding
    [SW48A2.kicad_pcb, SW48A2.sch]
2017-04-19 New netlist with lm5175 updated footprint
    [SW48A2.sch]
2017-04-19 Progress in routing
    Routed some of the passives
    [SW48A2.kicad_pcb, SW48A2.sch]
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2017-04-20 Deleting DAC and Reference
    Ciao Carlo!
    [basetta_digitale.kicad_pcb, basetta_digitale.sch]
2017-04-23 Shorted some wires for better performance
    [SW48A2.kicad_pcb]
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2017-04-24 Finish routing of basetta..
    Carlo must find something wrong...
    [basetta_digitale.kicad_pcb]
2017-04-30 Progress on lineare rev3
    Created the kicad project and some of the libs!
    [_saved_alimentatore.sch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]
2017-05-01 Progress on schematics
    DONE:
    -I2C insulation
    -DAC connection
    -DAC signal contitioning
    -Error amplifiers(both for voltage & current)
    -Pass element + gate control
    TBD:
    -Linear regulators for powering up the OPamps and the I2C glue logic
    [I2C&DAC.sch, _saved_alimentatore.sch, alimentatore.kicad_pcb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]
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2017-05-01 Revised work done by @NikoGela
    A few things have changed, to make it more clear schematic and routing changes are separated.
    #Schematic
    -removed the led that was used to show if the regulator was working
    -removed the power traces from the signal bus
    -broken out the connection for the I2C. see routing for futher details
    -changed the eletrolitic caps from THT to SMD
    #pcb layout
    -most of the changes done are reflecting the one applied on the schematic
    -apart from those, the linear regulator was moved to the right of the board, because by doing so the routing is easier
    The board is finished so the branch will be merged into master
    [_saved_basetta_digitale.sch, basetta_digitale.kicad_pcb]
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2017-05-05 Flipped board to adjust for final board stack
    [SW48A2.kicad_pcb]
2017-05-05 Final revision of schematic
    -added pullup resistor on i2c from digital side
    -added reference using lm4040. Our ic is the 2.5V version
    -checked the signal conditioning stage to get it working with changed reference
    WHEN TESTING IS POSSIBLE THAT THERE WILL BE SOME PROBLEMS WITH THE DAC & THE REFERENCE. The proposed solution is to cut the traces to the reference, use VDD as a reference and change the signal conditioning resistor.
    [I2C&DAC.sch, alimentatore.sch, logic_power.sch]
2017-05-05 Removed 75xx regulator from linear board
    In order to save space thoose components have been moved to the pd board
    [logic_power.sch]
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2017-05-05 Created solid ground planes
    Cause thermal relief is for kids
    [basetta_power_distribution.kicad_pcb]
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2017-05-07 Added ground planes, moved I2C connector
    The I2C connector was moved to accomodate the changes done in the lineare board
    [basetta_digitale.kicad_pcb]
2017-05-08 Swapped for LDO, ground planes
    [basetta_power_distribution.sch]
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2017-05-08 Adding hole for I2C bus in logic_power_distribution board
    [basetta_power_distribution.kicad_pcb]
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2017-05-22 Removed ground planes
    You can't see shit if they are off
    [alimentatore.kicad_pcb, basetta_digitale.kicad_pcb, basetta_power_distribution.kicad_pcb]

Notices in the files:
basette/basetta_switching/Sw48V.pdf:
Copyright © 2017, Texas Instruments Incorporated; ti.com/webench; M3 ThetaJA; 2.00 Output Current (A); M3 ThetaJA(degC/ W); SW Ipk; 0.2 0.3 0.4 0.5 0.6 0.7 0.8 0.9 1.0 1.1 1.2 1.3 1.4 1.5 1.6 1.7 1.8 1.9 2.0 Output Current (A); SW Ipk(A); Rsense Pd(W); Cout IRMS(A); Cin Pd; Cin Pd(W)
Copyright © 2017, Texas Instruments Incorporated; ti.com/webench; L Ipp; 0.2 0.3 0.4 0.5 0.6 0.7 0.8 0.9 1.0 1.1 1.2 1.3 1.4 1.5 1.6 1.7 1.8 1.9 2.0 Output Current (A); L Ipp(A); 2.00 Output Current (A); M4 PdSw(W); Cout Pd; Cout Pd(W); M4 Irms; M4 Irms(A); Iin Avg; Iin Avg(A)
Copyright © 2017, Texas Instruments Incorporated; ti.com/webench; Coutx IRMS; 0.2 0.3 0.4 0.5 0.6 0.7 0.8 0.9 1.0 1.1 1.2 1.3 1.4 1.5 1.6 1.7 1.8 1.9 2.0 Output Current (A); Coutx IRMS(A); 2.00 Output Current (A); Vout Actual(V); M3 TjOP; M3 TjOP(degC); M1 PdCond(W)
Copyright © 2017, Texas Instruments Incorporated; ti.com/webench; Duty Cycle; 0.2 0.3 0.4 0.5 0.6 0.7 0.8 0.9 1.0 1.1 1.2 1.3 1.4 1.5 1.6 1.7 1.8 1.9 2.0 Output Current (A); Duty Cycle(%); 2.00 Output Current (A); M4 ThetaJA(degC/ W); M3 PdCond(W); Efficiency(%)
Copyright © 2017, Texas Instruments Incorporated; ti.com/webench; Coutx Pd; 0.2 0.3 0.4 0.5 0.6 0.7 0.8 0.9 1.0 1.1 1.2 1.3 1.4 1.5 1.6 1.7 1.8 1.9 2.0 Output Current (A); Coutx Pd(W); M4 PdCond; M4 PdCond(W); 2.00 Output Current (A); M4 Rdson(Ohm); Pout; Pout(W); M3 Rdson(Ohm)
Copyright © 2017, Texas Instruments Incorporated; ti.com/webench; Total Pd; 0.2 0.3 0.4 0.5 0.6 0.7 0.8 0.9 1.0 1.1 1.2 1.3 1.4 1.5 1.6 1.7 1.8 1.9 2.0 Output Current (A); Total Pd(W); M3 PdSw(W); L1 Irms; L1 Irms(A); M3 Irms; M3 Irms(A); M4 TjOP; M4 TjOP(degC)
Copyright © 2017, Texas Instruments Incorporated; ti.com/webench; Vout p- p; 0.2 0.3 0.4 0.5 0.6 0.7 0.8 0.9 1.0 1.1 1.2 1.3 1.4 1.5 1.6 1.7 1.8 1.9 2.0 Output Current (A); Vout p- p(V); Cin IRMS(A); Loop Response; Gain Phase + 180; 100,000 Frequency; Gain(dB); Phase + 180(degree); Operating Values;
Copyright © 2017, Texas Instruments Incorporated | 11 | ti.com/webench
